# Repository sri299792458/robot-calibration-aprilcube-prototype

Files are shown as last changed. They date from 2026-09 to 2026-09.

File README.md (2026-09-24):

# G1 camera calibration and fixtures

Calibration capture and analysis tools, with printable marker mounts for the
head-mounted RealSense and Dex3 hands on the Unitree G1.

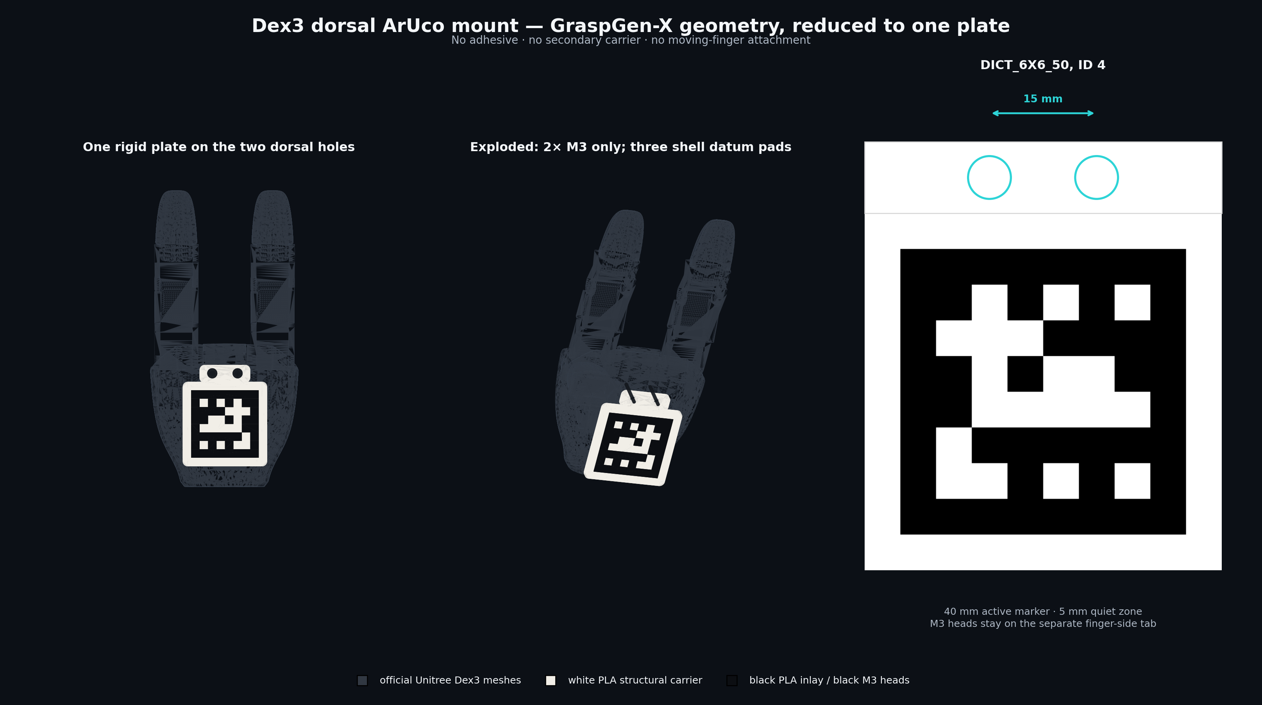
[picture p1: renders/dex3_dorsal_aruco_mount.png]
CAD view of the Dex3 dorsal marker mount, fasteners and marker geometry


*Right-hand wrist-marker mount: CAD placement and attachment geometry. See the
guide for photographs, print files and fitting details.*

**[Calibration workflow](https://sri299792458.github.io/g1-research-docs/calibration/workflow.html)** ·
[Full G1 guide](https://sri299792458.github.io/g1-research-docs/) ·
[Documentation source](https://github.com/sri299792458/g1-research-docs)

Use this repository to capture camera/joint observations, fit and evaluate a
calibration, or reproduce the wrist-marker fixtures. It includes both wrist
mounts, the selected August calibration bundle, and the later V7 torso mount
with R2 fit coupons. The V7 assembly still has
[physical fit limits](artifacts/g1_mount_v7/FIT_STATUS.md).

Physical cube stacking, control integration and episode recording live in
[g1-dex3-tabletop](https://github.com/sri299792458/g1-dex3-tabletop).
Generic printed targets and detection live in the
[AprilCube fork](https://github.com/sri299792458/aprilcube).

## Choose a starting point

| Task | Files to open |
| --- | --- |
| Print or fit a wrist marker | [Mount guide](docs/dex3_dorsal_aruco_mount.md), [right ID 4](cad/dex3_dorsal_aruco_mount/), [left ID 5](cad/dex3_dorsal_aruco_mount_id5/) |
| Inspect the current torso mount | [V7 guide](artifacts/g1_mount_v7/README.md), [physical fit status](artifacts/g1_mount_v7/FIT_STATUS.md), [R2 coupons](artifacts/g1_coupon_r2/README.md) |
| Edit native torso CAD | [Fusion/mesh script guide](scripts/G1_MOUNT_README.md), [native archive](artifacts/g1_mount_v7/cad/G1_calibration_mount_native.f3d), [STEP](artifacts/g1_mount_v7/cad/G1_calibration_mount_assembly.step) |
| Inspect the selected calibration | [Bundle guide](docs/calibration-bundle.md), [bundle JSON](config/calibrations/dex3_shared_20260812_selected_free.json) |
| Understand capture and native fitting | [CLI reference](docs/calibration-cli.md), `src/g1_aprilcube_calibration/session_store.py`, `dataset_builder.py`, `robot_calibration_bridge.py`, `calibration_evaluation.py` |
| Understand control handback | [Commissioning evidence and recovery](docs/g1_control_state_and_recovery.md), [current guide](https://sri299792458.github.io/g1-research-docs/control/ownership.html) |

## What is established

The wrist targets use 40 mm `DICT_6X6_50` markers, right ID 4 and left ID 5.
Their matched profiles enforce the arm and marker identity. The two palm frames
have different dorsal directions; use the handed transforms in
`src/g1_aprilcube_calibration/dex3_dorsal_mount.py`.

The August 12 bundle preserves the shared-camera fit and selected joint offsets
used by the August 25 stacking baseline. Its original validation record reports
model-fit evidence, not an independent accuracy specification for another robot.
The bundle materializes a separate calibrated URDF and checks the original
URDF's hash. It does not require the original recordings to be present.

V7 is the current torso structure: two broad crossbars and two side plates
supporting the existing 210 × 300 mm carrier. Its 180 × 270 mm ChArUco pattern
and four M4 holes are preserved. Recorded CAD checks are available alongside
the exports. **The complete V7 assembly has not been physically qualified.**
Upper M6 × 25 worked in the reported R2 coupon trial; lower M6 × 25 did not
engage through the coupon. Lower screw length, upper engagement details,
assembly stiffness, reinstall repeatability and calibration accuracy remain
unresolved. Consult the fit status before choosing hardware.

The pre-R2 meshes under `original_reference/` and `precision_reference/` are
inputs to the comparison checks. Current print files are under `print_parts/`
and `fit_coupons/`; reference meshes are not alternative current designs.

## Offline setup

CAD exports and the supplied Bambu projects can be opened without installing the
Python package. The Python tools expect two independent checkouts at the root:

```bash
git clone https://github.com/sri299792458/aprilcube.git aprilcube
git -C aprilcube checkout --detach 80ed7c72ed00aef6dc70f77d8169a199e9a612cd
git clone https://github.com/unitreerobotics/unitree_ros.git unitree_ros
git -C unitree_ros checkout --detach f3772ce54c56ef2d34c6aee8100bc768896c7d19
uv sync --python /usr/bin/python3 --group dev
```

These are the revisions used by the inspected calibration checkout. Keep the
system interpreter aligned with ROS for later hardware use: Python 3.10 for
Humble or Python 3.12 for Jazzy, with NumPy 1.x. The editable AprilCube dependency
and its models must be available before `uv sync`.

An offline bundle inspection creates no robot connection:

```bash
.venv/bin/g1-calib inspect-calibration-bundle \
  --calibration-bundle config/calibrations/dex3_shared_20260812_selected_free.json \
  --urdf config/urdf/g1_29dof_rev_1_0_g1pilot_collision.urdf
```

The Fusion scripts require Autodesk Fusion's `adsk` API. Mesh checks and Bambu
comparisons have additional dependencies described in their
[script guide](scripts/G1_MOUNT_README.md). Running a CAD builder changes its
active design; opening an exported model does not require running a builder.

## Repository boundaries

`src/`, `tools/`, and `tests/` retain the calibration implementation and its
regressions. `config/` contains matched profiles and upstream pins. `cad/` and
`artifacts/` contain the current fixtures, their source assets and recorded CAD
checks. The included tests are offline contracts; passing them does not
commission a hardware command or validate a physical mount.

Raw recordings, experiment work directories, private running notes and internal
design proposals are kept outside the public tree. Paths under `sessions/`,
`runs/`, or `work/` in provenance identify retained source evidence; they are not
downloads bundled with this repository. Selected manipulation datasets are
released separately in LeRobot format after conversion and review.

Generated handoff ZIPs are not duplicated in Git. The packaging scripts can
assemble them from the maintained files. Existing upstream notices, including
the Unitree model license with the frozen V7 inputs, remain with those assets.

Research and original implementation by
[sri299792458](https://github.com/sri299792458), building on Unitree, AprilCube
and Mike Ferguson's `robot_calibration`. This consolidation retains the V7
implementation and the local calibration-bundle addition without importing
private development history.

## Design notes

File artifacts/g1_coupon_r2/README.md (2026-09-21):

# Compact G1 fit coupons — R2

Use these revised coupons for the first shell-fit and M6 screw-reach check. All four together are estimated at **19.8 g and 43 minutes**, versus **61.6 g and 100 minutes** for the original coupons with the same settings. That is approximately **68% less filament**. These are Bambu Studio estimates, not a completed print measurement.

The full 28 × 28 mm curved contact patch, 6.8 mm M6 bore, and original washer bearing position are retained. The old 34 mm outer block and deep access well are removed. Upper coupons are now about 22.5–22.8 mm high; lower coupons about 15.1 mm. The four structural mount parts are unchanged.

## Physical fit status

These coupons have now been tried. The user reports M6 × 25 works at the upper locations but does not engage at the lower locations with coupons installed. Lower screw length is unresolved, upper engagement and washer details are unmeasured, and all four CAD seats remain 12 mm at the screw axis. The M6 × 20 example below is nominal geometry, not a hardware recommendation. See [FIT_STATUS.md](FIT_STATUS.md).

## Print

Open `G1_R2_fit_coupons.3mf` in Bambu Studio for all four coupons on one plate, or load the individual STLs in `print_parts/`. Keep the supplied orientation and 100% scale. The marked flat face goes on the bed; the curved face prints upward.

The supplied profile uses an H2D with a 0.4 mm standard nozzle, Bambu PLA Basic, 0.20 mm layers, **three walls, 10% gyroid infill and four top/bottom layers**, without supports or a brim. Use the actual filament profile for your material before printing; its time estimate can differ. The engraved marks span at most 4 mm on the underside and create small bridges. The main M6 bore is vertical in print orientation.

## Identify and fit

The triangle on the flat washer side points toward the robot's head when installed. Dots on that same side identify the location:

| Dots | Robot location |
| ---: | --- |
| 1 | Upper left |
| 2 | Upper right |
| 3 | Lower left |
| 4 | Lower right |

Left/right refer to the robot's own sides. `renders/identification_marks.png` shows the markings.

Place the curved face against the matching location on the installed silver shell, arrow upward. Use the intended M6 screw and washer, and tighten only gently for the fit check. Check for rocking and verify usable thread engagement and clearance before the screw bottoms out. These coupons retain the nominal 12 mm center stack: M6 × 20 with a 1.6 mm washer projects approximately 6.4 mm beyond the modeled outer shell, before subtracting any unmeasured insert recess.

These are individual fit gauges. They do not validate the assembled crossbar's hole spacing, simultaneous seating, deep tool access, stiffness or calibration accuracy.

## Verification

All four STLs are watertight single solids and sit at Z = 0 in their print files. The CAD revision only trims away material in front of the contact patch and outside its footprint, then adds shallow markings away from the washer. Across 1,592 contact samples per coupon, the revised meshes agree with fresh exports of the original crossbars within 0.038 mm (0.05 mm comparison tolerance); all 96 sampled washer-seat points per coupon agree, and every screw centerline is clear. Native Fusion has no feature errors or warnings. Detailed records are in `geometry_qa.json` and `slicer_comparison.json`.

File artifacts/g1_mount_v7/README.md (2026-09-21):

# G1 torso calibration mount — native Fusion redesign

Status: mechanically motivated CAD prototype for stationary calibration. The four structural parts have passed the recorded geometry and clearance checks. R2 coupons have been printed and tried: M6 x 25 reportedly works at the upper locations but does not engage through the lower coupons. Lower screw length, full assembly fit, stiffness, repeatability and calibration accuracy remain unresolved. See [physical fit status](FIT_STATUS.md).

## Design decision

Use two torso crossbars and two flat side plates. The accepted 210 × 300 mm carrier, its four existing M4 holes, the 180 × 270 mm ChArUco pattern and its nominal placement are unchanged.

The failed design had a small offset connection to an M6 boss, which broke during support removal/handling in PLA. This redesign puts each 28 × 28 mm shell seat directly into a continuous crossbar. The side plates have approximately 18 mm rails, a broad rear spine, rounded windows, and fully backed 28 × 12 mm carrier tabs.

The four-part architecture is a deliberate print-orientation choice. Side plates lie on their exterior faces; crossbars lie on their forward faces. The principal long members then lie in their print layers. An integral two-frame alternative reduces screw count but makes the lateral torso attachments harder to orient favorably. The four-part layout is the current recommendation for calibration, not a claim that it is globally optimal.

Eight additional M5 bolts attach the four side-plate/crossbar junctions, two bolts per junction with 20 mm spacing. These are fixed assembly joints. There are no adjustment slots or extra carrier holes. Splitting parts to improve print orientation follows the general approach described in [Prusa's design-for-printing guidance](https://help.prusa3d.com/article/modeling-with-3d-printing-in-mind_164135).

## Files

- `cad/G1_calibration_mount_native.f3d`: native Fusion archive with named sketches, extrusions, lofts, construction planes, imported reference meshes and hidden fit coupons.
- `cad/G1_calibration_mount_assembly.step`: four structural solids in their assembled positions. Reference meshes and hidden coupons are excluded.
- `print_parts/`: four centered, correctly oriented structural STLs, one copy each.
- `fit_coupons/`: four compact R2 interface coupons, centered on the bed. Their full contact patches, M6 bores and washer bearing planes are retained from the crossbars. The unused front block and access wells are removed. See `fit_coupons/README.md` for identification marks and coupon settings.
- `renders/fusion_assembly.png`: assembly shown in Fusion, with the existing board and robot as references.
- `renders/board_connections.png`: centered rear view showing the four board mounting pads.
- `renders/m6_root_section.png`: section through the upper-left M6 connection.
- `renders/print_orientations.png`: broad faces to place on the bed.
- `design_inputs.json`: dimensions, frozen interfaces, camera/board placement and nominal shell samples.
- `mesh_and_clearance_qa.json`, `fusion_assembly_qa.json`, `fusion_interference_qa.json`, `board_contact_qa.json`: verification records.

The original accepted board is included in the Fusion file as reference geometry. It does not need reprinting. Mesh references are not converted into a new optical pattern.

The supplied carrier STLs use print-bed coordinates, translated +15 mm along both board-plane axes. The final Fusion assembly reverses this offset before applying the optical-board transform. Earlier assembly previews omitted that conversion and showed the carrier shifted relative to its supports; the final archive and included previews are corrected.

## Hardware

| Use | Quantity | Hardware |
| --- | ---: | --- |
| Upper torso mounting | 2 | M6 × 25 socket-head screws under physical test; engagement and washer stack unmeasured |
| Lower torso mounting | 2 | M6 socket-head screws; length unresolved. M6 × 25 does not engage through the R2 coupons |
| Torso washers | 4 | M6 flat washers, approximately 1.6 mm thick, maximum 13 mm OD |
| Existing board attachment | 4 | M4 × 30 socket-head screws |
| Board washers and nuts | 8 + 4 | M4 flat washers and M4 nyloc nuts |
| New frame joints | 8 | M5 × 30 socket-head screws |
| New frame washers and nuts | 8 + 8 | M5 flat washers, approximately 1 mm thick, and standard M5 hex nuts |

The M5 nut slots are 4.4 mm thick and 8.3 mm across the retaining flats. They are for ordinary approximately 4 mm thick M5 hex nuts, not taller nyloc nuts. Load the nuts through the forward-facing slots and insert each bolt from the exterior of the side plate.

The M5 stack leaves approximately 3.8 mm of bolt protrusion beyond the modeled inner nut face. Check the actual nut/washer dimensions before assembly. All tightening is through washers and printed material; use a short hand tool and stop before compressing or deforming the print. Witness-mark the joints and inspect for loosening.

The earlier M6 × 20 assumption is superseded by the physical results. No deeper lower washer recess or M5 × 20 conversion has been made. See [FIT_STATUS.md](FIT_STATUS.md) before selecting hardware.

### M6 reach is not the same as engagement

At each M6 center the modeled shell-to-washer-face distance is 12 mm. A 20 mm screw with a 1.6 mm washer therefore projects about **6.4 mm past the modeled outer shell**. Actual threaded engagement is reduced by any recess before the first usable thread. The handoff does not measure that recess or the blind-hole clearance.

Do not assume 6.4 mm of thread engagement, use screw bottoming as a datum, or substitute a longer screw without measuring the usable depth. A screw that merely begins to clamp is not proof of adequate engagement. Record both thread-start depth and available bottom clearance with each fit coupon before finalizing the M6 length.

## Print and assembly

1. Print the four compact R2 fit coupons first, using 0.20 mm layers, three walls, four top/bottom layers and 10% gyroid infill in PLA. Each retains the seating face, M6 bore and washer bearing plane. The deep tool well is removed. Fit the matching coupon with its arrow pointing up and the normal silver shell installed. Dot counts identify 1 upper-left, 2 upper-right, 3 lower-left, 4 lower-right, using the robot's own left/right.
2. Check full seating without rocking, adequate measured screw engagement and clearance before bottoming. The shell must not shift or spring against internal foam under light clamping. Compact coupons test individual seats and screw reach; the full crossbar hole spacing, simultaneous seating and deep tool-access corridors still need checking with the actual crossbars.
3. After the coupons pass, print the four structural STLs in their provided orientations. Centering in the slicer is fine; preserve rotation and 100% scale. One side plate per bed. Both crossbars can share a bed if the slicer confirms spacing.
4. Start with PLA or PLA+, 0.20 mm layers, six walls, six top/bottom layers and 35% gyroid infill. These are starting settings, not a tested printer profile. There are no detached bosses or large unsupported carrier tabs. Inspect the short horizontal holes and the M6 counterbore ceilings in the slicer; small bridges remain. Do not enable support that will be trapped in a well or nut slot.
5. Assemble the crossbars and side plates loosely with the eight M5 bolts. Fit the existing board against the four carrier tabs and install its four M4 bolts, washers and nyloc nuts. Keep all joints loose until every interface seats naturally; do not pull misaligned parts together with screw torque.
6. Mount on the stationary robot, then snug the joints progressively without bowing the board or crushing the PLA. Record the tightening sequence and witness marks for repeatable reassembly.

The side plates measure approximately 238.1 × 271.4 × 34.5 mm in print orientation. Upper and lower crossbars measure 230 × 40 × 53.1 mm and 230 × 40 × 37.6 mm. All fit within the handoff's conservative 300 × 320 mm bed area.

PLA remains the baseline. A change to PETG changes stiffness and printing behavior and does not replace the fit and flex checks. The fixture is for stationary calibration; remove it before robot walking, waist motion or arm trajectories.

## Recorded CAD checks

- Four structural STLs and four coupons: watertight, consistently oriented, one connected solid each.
- Native Fusion timeline: no feature errors or warnings at export.
- Four native structural solids: zero volume interference; coincident mating faces excluded.
- Full active target: 49,051 rays at 1 mm spacing from the supplied fitted camera pose, zero obstruction.
- Four M6 corridors: a sampled 14.4 mm diameter, 90 mm long straight approach is clear.
- Four M4 locations: optical-side and rear nut approach centerlines are clear.
- Existing carrier to support pads: all four screw centerlines align; 72 sampled points around each hole match the carrier's bearing face within 0.02 mm mesh tolerance. This checks nominal CAD contact, not printed fit.
- Eight M5 centerlines: plate and crossbar holes are aligned and clear.
- Nominal shell approximation: 96 contact samples per root; maximum absolute sampled difference from the public shell is approximately 0.113 mm. This is only CAD approximation error, not physical robot accuracy or a complete surface-tolerance certification.

R2 coupon fit observations are recorded in FIT_STATUS.md. No FEA, complete V7 structural assembly trial, creep test, measured stiffness test or calibration capture has been performed. The full-density structural CAD volume corresponds to about 1.01 kg of PLA at 1.25 g/cm³, excluding the accepted carrier and metal hardware. This is an upper bound for solid prints, not a slicer mass estimate. The corresponding structure-only gravity moment about the M6 pattern is approximately 0.78 N·m; it is not a load rating.

## Calibration acceptance for tabletop work within a few millimetres

The intended camera extrinsic remains:

`torso_T_camera = torso_T_board × inverse(camera_T_board)`

The nominal board center is `[245, 0, 127.5]` mm in `torso_link`, pitched +21° about torso y. The active outer top-left corner defines the OpenCV board origin. The complete transform is in `design_inputs.json` in millimetres; convert translation to metres when using the calibration code.

Use these as initial acceptance targets, not achieved specifications:

- Active pattern dimensions remain 180 × 270 mm; measure both axes and diagonals. Check mounted face bow, initially targeting less than 0.5 mm.
- Live rectified color detects all 27 markers and 40 ChArUco corners without fixture obstruction.
- With the camera fixed, collect stationary bursts across at least five full fixture removal/reinstall cycles. Aim for board-pose variation below 0.5 mm and 0.1°. If it exceeds those targets, investigate seating, shell compliance, bolt slip and board flex before accepting the calibration.
- A 0.1° rotation error produces about 0.87 mm lateral error at 0.5 m, before translation and other errors. Evaluate the budget at the actual working distance.
- Reinstall repeatability does not establish absolute accuracy. Independently check the installed board's relationship to a torso datum and validate the result on a separately measured tabletop target or task points. Neither CAD coordinates nor low image reprojection error alone prove millimetre accuracy.

The interface remains nominal until the physical observations are recorded. Keep those observations and the installed transform separate from the source CAD values.

## Editing

The four structural parts are native solids with editable feature history. The supplied Python builders make the fixed interface coordinates explicit. Changing an extrusion or sketch can invalidate the assembled mating faces, screw stack or optical clearance; regenerate and rerun the checks after geometry changes. The single plate-thickness user parameter is not a complete assembly-level constraint system.

The packaging scripts can generate a review ZIP with copies of the V7 scripts in `source/`; generated ZIPs are kept outside Git. Their paths resolve from the repository checkout; they are not a one-click installer. Frozen inputs are in `reference_inputs/`; geometry construction runs inside Fusion. See [the repository script guide](../../scripts/G1_MOUNT_README.md) for dependencies and execution context. Scripts included under `source/` in a generated ZIP are provenance copies; run them from the repository `scripts/` folder. The native F3D file is self-contained and can be opened without these scripts or Python dependencies. For slicing, use `print_parts/` and `fit_coupons/`; the raw STLs under `cad/` retain their modeling coordinates.

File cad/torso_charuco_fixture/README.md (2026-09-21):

# Accepted printed carrier

This folder contains only the accepted carrier used by the
[current V7 torso mount](../../artifacts/g1_mount_v7/README.md):

- `carrier_white_body.stl`
- `carrier_black_inlay.stl`
- `carrier_multicolor_h2d.3mf`
- `design_manifest.json`: carrier definition and frozen mounting coordinates

The already printed carrier does not need to be printed again. Its original
mesh and 3MF bytes are unchanged. The previous V6 side frames, coupons and
generator have been removed. The current structural parts and fit coupons
are in `artifacts/g1_mount_v7/` and `artifacts/g1_coupon_r2/`.

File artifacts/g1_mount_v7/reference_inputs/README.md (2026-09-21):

# Geometry inputs for the current mount

Carrier geometry and mounting coordinates derive from source commit
`b555c3adea33966607c26837264230dbc1208c6c`; see `PROVENANCE.md`.
The carrier meshes match the retained accepted meshes under
`cad/torso_charuco_fixture/`. The manifest has been reduced to the carrier
definition and frozen input coordinates; previous frame and hardware
instructions are removed. `reference_code/config/torso_fixture_layout_camera.json`
matches the repository's measured camera configuration semantically.

The robot mesh and URDF reference files carry the upstream license included
as `robot_model/UNITREE_ROS_LICENSE`. This partial snapshot is sufficient
for the mount scripts, not a complete robot simulation model.

Use `../README.md` and `../FIT_STATUS.md` for current design and hardware status.

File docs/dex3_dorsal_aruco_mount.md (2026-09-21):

# Dex3 two-hole dorsal ArUco mount

## Result

The mount is a **single 50 x 50 mm optical plate with a centered 30 x 10 mm
finger-side mounting tab**, fixed directly to the two holes in the rigid Dex3
palm shell. Its overall envelope is 50 x 60 mm. It carries a two-filament 40 mm
`DICT_6X6_50` marker, right ID 4 or left ID 5. There is no tape, intermediate bracket, snap joint,
or attachment to a moving finger.

This is the pitch-corrected second revision. The first physical print proved
that the former 2.0 mm wrist pad did not contact the hand. That design assumed
the plate was parallel to the palm-link plane. The local M3 mounting surface is
actually pitched by approximately 1.143 degrees. Revision 2 follows that pitch
and uses a 2.57 mm third datum on the flatter central shell region.

Rendered mount on the official Dex3 geometry

The printable H2D file is
[`dex3_dorsal_aruco_mount_multicolor_h2d.3mf`](../cad/dex3_dorsal_aruco_mount/dex3_dorsal_aruco_mount_multicolor_h2d.3mf).
Print the small
[`m3_15mm_fit_coupon.stl`](../cad/dex3_dorsal_aruco_mount/m3_15mm_fit_coupon.stl)
first.

### Left and right files

Use separate IDs when both hands can appear in the image. The mechanical
envelope and mounting hardware are shared; the detector profile and palm-frame
transform are handed.

| Hand | Marker | CAD directory | Matched target profile |
| --- | --- | --- | --- |
| Right | ID 4 | `cad/dex3_dorsal_aruco_mount/` | `config/dex3_dorsal_aruco_target.json` |
| Left | ID 5 | `cad/dex3_dorsal_aruco_mount_id5/` | `config/dex3_left_dorsal_aruco_id5_target.json` |

Generate the left files from the repository root without replacing the right:

```bash
.venv/bin/python tools/generate_dex3_dorsal_aruco_mount.py --marker-id 5 --side left
```

Check the `side` field and transform in each generated `design_manifest.json`.
The right marker faces toward negative palm Y; the left faces toward positive
palm Y. The ID 4 examples and numeric transform below describe the right hand;
use the left profile and generated transform for ID 5.

## What is established, and what is inferred

The design does not pretend that the public Unitree model contains data that it
does not contain.

| Item | Status | Evidence |
|---|---|---|
| Target family | Established | The marker in the original GraspGen-X project video decodes as OpenCV `DICT_6X6_50`, ID 4, across multiple frames. |
| Target form | Established | Video frames show a flat, roughly 50 mm dorsal plate on the right Dex3. |
| Palm frame and outside surface | Established | Official Unitree `right_hand_palm_link.STL` and Dex3 URDF. The central dorsal region is shallowly curved: less than 0.9 mm departure from a plane over the proposed footprint. |
| Two physical holes | Established | Supplied photograph of the actual Dex3. |
| Hole pattern | **Official dimension** | Unitree's Dex3-1 user manual calls out `2 x M3`, 3 mm deep, on 15.00 mm centers. An M3 screw was also checked directly in the real hand. |
| Hole midpoint in `*_hand_palm_link` | **Official drawing + official mesh** | The manual places the pair centerline 66.70 mm from the wrist-side datum and on the hand centerline. The URDF/mesh establishes that as palm `[x, z] = [66.70, 0] mm`; ray intersection gives the dorsal shell at approximately `y = -21.33 mm`. |

The tiny coupon remains useful because FDM holes often print undersize. It now
checks printer clearance against an official 15.00 mm pattern rather than
testing an image-derived estimate.

The reproducible measurements are recorded in
[`graspgenx_dex3_mount_evidence.md`](../references/graspgenx_dex3_mount_evidence.md).
The raw downloaded video was analysis material and is not required by the CAD.
That evidence record also documents the search of Unitree's public CAD, model,
URDF, USD, historical mesh releases, and the image-based Dex3 user manual. The
URDF mesh omits the holes, but the manual supplies their missing dimensions.

## Geometry

| Feature | Dimension |
|---|---:|
| Carrier envelope | 50 x 60 x 4.0 mm |
| Optical square / centered mounting tab | 50 x 50 mm / 30 x 10 mm |
| Corner radius | 3.0 mm |
| Active ArUco square | 40.0 mm |
| Quiet zone | 5.0 mm on every side |
| Marker grid | 6 x 6 payload + one-cell black border |
| Cell size | 5.0 mm |
| Black inlay depth | 0.6 mm |
| Hole center spacing | 15.00 mm, official drawing |
| Hole pair centerline from wrist datum | 66.70 mm, official drawing |
| Blind-hole specification | 2 x M3, 3.0 mm deep |
| Through clearance | 3.4 mm |
| 90-degree countersink | 6.0 mm major diameter, 1.7 mm deep |
| Screw-line distance from finger-side tab edge | 5.0 mm |
| Material ligament around each 6 mm head, fore/aft | 2.0 mm / 2.0 mm |
| Local mounting pitch from palm STL | 1.143 degrees |
| Rear screw bosses | 7.0 mm diameter x 1.5 mm high |
| Rear stabilizing datum | 6.0 mm diameter x 2.57 mm center height |
| Stabilizing datum location | 20.0 mm from wrist-side optical edge |
| Stabilizing datum face correction | 1.994 degrees relative to plate |

The screw centers are on the separate 10 mm tab. Even the complete 6 mm heads
remain beyond the 50 mm optical square, so neither the black border nor its 5 mm
white quiet zone is interrupted. The line of screws sits next to the finger
bases and the complete marker extends toward the wrist. This keeps both metal
heads and the target away from the moving finger links.

The 10 mm tab depth is intentionally not reduced further. A centered 6 mm
countersink leaves 2 mm of PLA toward the optical plate and 2 mm toward the
outer edge. Reducing the overall length to 58.5 mm would save only 1.5 mm while
cutting the marker-side ligament to 0.5 mm, an undesirable stress concentration
next to a clamped countersunk screw.

The two annular screw bosses and one central circular pad form a three-point
seat. This is deliberate: the official shell is curved, so a nominally flat
back would rock or bend when tightened. Three small hard datums are the usual
fixture-design solution because they establish one plane without overconstraint.
The third datum is now only 35 mm from the screw line rather than 45 mm. It is
still wristward of the marker center, so the marker's center lies inside the
support triangle, but the pad no longer reaches onto the more strongly curved
wrist end of the shell.

The palm-STL tangent over the two screw-boss footprints has `dy/dx = 0.019947`.
The fitted tangent over the third pad is `dy/dx = -0.01485`. Those two slopes
set the installed plate pitch, the 2.57 mm pad height, and its angled contact
face. The nominal pad-center discrepancy from the STL surface is below 0.001
mm; printing tolerance, not the CAD equation, is now the limiting factor.

## Exact hardware

Use:

- 2 x **M3 x 8 mm, ISO 10642, 90-degree countersunk socket-head machine
  screws, black oxide**;
- one 2.0 mm hex key;
- white PLA and matte black PLA.

The printed stack from the flush head face to the hand shell remains 5.5 mm: 4.0 mm
plate plus a 1.5 mm rear boss. An M3 x 8 screw therefore enters by 2.5 mm,
leaving 0.5 mm before the conservative 3.0 mm blind-hole bottom. Do not
substitute M3 x 10: it can bottom in the blind hole. Do not use a washer; the
countersunk head is the intended plate datum.

The thread size has already been confirmed with an M3 screw. When assembling,
still start both screws by fingers only; this avoids cross-threading the shallow
blind holes.

## Print on the Bambu H2D

1. Print the fit coupon in any PLA using a 0.4 mm nozzle and 0.20 mm layers. It
   should take only a few minutes and checks printer tolerance and center
   spacing, not the already-confirmed thread designation.
2. Put two loose M3 screws through the coupon. Both screws must enter the hand
   holes without bending the coupon or pushing either screw sideways.
3. Open the multicolor 3MF as one object with two parts. Assign
   `carrier_white_PLA` to white and `aruco_black_PLA` to matte black.
4. Keep the generated orientation: the marker face is on the build plate and
   the three datum pads point upward. A smooth PEI plate gives the cleanest
   optical face. No support is required.
5. Use a 0.20 mm layer height, four walls, and at least five top/bottom layers.
   The 0.6 mm inlay occupies exactly three nominal layers.
6. Do not rescale either part and do not separate their origins.

Separate white and black STLs are included for slicers that do not preserve the
3MF material assignment.

## Assembly

1. Power the robot off and make sure no finger can move.
2. Place the plate with the screw line toward the finger bases and the long
   portion of the plate extending toward the wrist.
3. Start both M3 x 8 screws by hand before tightening either one.
4. Tighten alternately with the short end of the 2.0 mm key. Stop as soon as all
   three rear pads are seated and the plate no longer rocks. This is a marker,
   not a structural payload bracket; high torque only risks the Dex3 threads.
5. Verify that the plate clears both proximal finger links throughout their
   slow, powered-off manual range before commanding the hand.
6. In the detector, configure `DICT_6X6_50`, ID 4 (right) or ID 5 (left), and a marker side length of
   exactly `0.040` metres.

After assembly, take one close photograph square to the marker. The detector
must recover the intended hand's ID with all four corners. The screw heads are outside the optical
square and should never enter the detected quadrilateral.

## Marker transform

The generated manifest records this nominal target frame:

```text
marker +x = [ 0,          0,          1 ] in the palm frame
marker +y = [-0.999801,  -0.019943,   0 ] toward the wrist
marker +z = [ 0.019943,  -0.999801,   0 ] outward from the marker face

palm translation to marker center = [0.03681565, -0.02742720, 0.0] m
```

The longitudinal and lateral coordinates come from Unitree's official
dimensioned drawing, not photograph registration. The outward coordinate and
1.143-degree plate pitch use the official palm mesh at the documented hole
positions. This is the transform to use for the planned camera-only solve after
the physical seating and fixed-transform validation checks. Keep the optional
joint camera/marker solve available as a diagnostic comparison rather than the
production result.

The CAD is parametric. After measuring a different center spacing, regenerate
it with:

```bash
uv run python tools/generate_dex3_dorsal_aruco_mount.py \
  --hole-spacing-mm MEASURED_SPACING
```

The generated plate occupies a local 50 x 60 x 6.675 mm print envelope before
its palm-frame mounting transform is applied. Add the resulting pitched object
to any motion-planning model before using the marked hand near the torso, table,
or the other arm.

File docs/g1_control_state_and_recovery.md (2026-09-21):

# G1 control state and debug-lowcmd recovery

This is the operator runbook for the control behavior physically observed on
this G1. Keep the distinction between the active **motion service**, the
locomotion **FSM ID**, and LowState `mode_machine`; they are different state.

## State vocabulary

| State | Meaning on this robot |
|---|---|
| Motion service `{"form": "0", "name": "ai"}` | The normal Unitree high-level controller is active. The wireless remote and G1 locomotion client can request FSM transitions. |
| No active motion service | Unitree `ReleaseMode()` has made direct debug `rt/lowcmd` ownership available. This is not an FSM such as Damp or Seated. |
| FSM 0 | Zero-torque state observed when the `ai` service was restored after a failed debug session. |
| FSM 1 | Damp. |
| FSM 3 | Seated. |
| FSM 4 | Regular/Ready on this robot. |
| LowState `mode_machine=5` | The 29-DoF G1 machine/joint layout. It is not locomotion FSM 5. |

Selecting the `ai` motion service does **not** select Damp, Seated, Ready, or
Walking. It only makes the high-level controller available. An explicit FSM
request and a read-back are still required.

## Why the remote can become unresponsive

The seated tabletop controller follows Unitree's debug architecture:

1. verify the robot starts in seated FSM 3;
2. call MotionSwitcher `ReleaseMode()` to deactivate `ai`;
3. publish a complete measured-state 29-joint command on `rt/lowcmd`; and
4. before closing that publisher, restore `ai` and explicitly verify the
   requested terminal FSM.

While `ai` is released, the wireless remote has no active high-level controller
to receive its FSM requests. The G1 locomotion client's read-only `get_fsm_id`
may also time out. This does not by itself indicate a failed Ethernet link or a
dead remote.

If the lowcmd process exits without restoring `ai`, both of these can be true at
once:

- no laptop lowcmd writer remains; and
- no normal Unitree motion service is active.

The result looks like a zero-torque/debug state and the remote cannot select
another FSM until `ai` is restored.

## Hardware observation: 2026-08-10

The zero-displacement seated commissioning run established the following:

- PC2 verified initial seated FSM 3;
- the dynamic handoff passed;
- the laptop released the active service;
- the first complete measured-state `rt/lowcmd` packet was accepted; and
- no changing joint target was part of the test.

The run then failed because PC2 stopped receiving the laptop heartbeat. Its
fallback attempted to restore the motion service, but MotionSwitcher read-only
API 1001 (`CheckMode`) timed out three times. PC2 therefore could not proceed to
a verified Damp request. The lowcmd process exited with `ai` still released,
and the wireless remote could not change modes.

Restoring `ai` from the laptop with Unitree's official SDK succeeded and
reported:

```text
motion service restored: {'form': '0', 'name': 'ai'}
```

The robot then entered the observed zero-torque FSM 0. It did not automatically
enter Damp or return to Seated. The wireless remote became usable again.

This run proved zero-displacement debug takeover, but at that point it did
**not** commission normal seated restoration, heartbeat-loss zero-torque
recovery, or changing-target arm motion. The later lifecycle checks recorded
below closed the first two gaps.

A second zero-displacement run after the first software changes narrowed the
failure further:

- PC2's new read-only preflight succeeded while `ai` was active and reported
  `motion_switcher=ai` together with seated FSM 3;
- the heartbeat guard covered `ReleaseMode()` and completion of the first
  measured-state lowcmd write;
- the first packet again passed and no changing target was commanded;
- the heartbeat nevertheless expired during the subsequent hold; and
- once `ai` had been released, PC2 MotionSwitcher API 1001 timed out again on
  every fallback attempt.

This established an important asymmetry on the installed stack: PC2's ROS
MotionSwitcher path could answer `CheckMode` before service release but could
not be relied upon to answer after release. The laptop's raw Unitree SDK did
successfully verify the released state during takeover and later restored
`ai`. The watchdog therefore stopped using the PC2 ROS MotionSwitcher path for
debug recovery. It creates a persistent client from the pinned raw SDK runtime
before takeover and reuses that same client after release. This replacement was
installed and tested offline before the later physical lifecycle checks
commissioned its post-release behavior.

A third zero-displacement run used that private raw-SDK runtime. It established
four additional facts:

- PC2 received one ping and expired at 0.500258 seconds, while the laptop later
  reported a maximum send gap of 0.922032 seconds;
- the gap occurred before takeover during blocking laptop-side MotionSwitcher
  client and lowcmd-publisher initialization, not during the 250 Hz hold loop;
- PC2's raw `SelectMode("ai")` request did take effect—the robot returned to its
  observed zero-torque state and the remote became responsive—even though the
  RPC reply was reported as status 7002; and
- the subsequent automatic Damp RPC did not complete.

Accordingly, every non-commanding local DDS endpoint is now initialized before
the short PC2 heartbeat lease is armed. Debug-lowcmd failure recovery no longer
chains an automatic Damp request after AI restoration. It restores `ai` and
requires the locomotion service to report FSM 0. The standing `rt/arm_sdk`
workflow retains its independently commissioned terminal Damp fallback.

A fourth zero-displacement run then verified the heartbeat correction:

- the laptop sent 34 pings with a maximum gap of 0.104117 seconds, safely below
  the 0.5-second PC2 lease;
- no heartbeat timeout occurred;
- PC2 restored `ai` and repeatedly read FSM 0; and
- a direct Sit request did not change FSM 0 to FSM 3.

This supports the operator's transition model: clean seated restoration must
use `FSM 0 -> Damp/FSM 1 -> Sit/FSM 3`, verifying every state. This chain is
used only after the arm has returned to the measured, table-supported start.
Fault or heartbeat-loss recovery stops at verified FSM 0 and does not continue
through Damp or Sit. If clean restoration reaches FSM 1 but cannot reach FSM 3,
the installed PC2 locomotion client supports an explicit ZeroTorque request so
cleanup can return to verified FSM 0.

The final two zero-displacement commissioning runs passed both terminal
lifecycle paths:

- normal completion reported `PC2 verified AI FSM 0 -> 1 -> seated FSM 3
  before the lowcmd publisher closed`; and
- deliberate heartbeat loss reported `PC2 verified AI service in zero-torque
  FSM 0 before the lowcmd publisher closed`.

Both runs had already passed dynamic handoff, service release, the first
complete measured-state lowcmd packet, and the zero-displacement hold. These
results physically commission debug ownership, normal seated restoration, and
independent heartbeat-loss recovery. They did not claim changing-target motion;
at that point the first fully preflighted tabletop route was still the next
changing-target seated test. The reviewed repository configuration now sets
`control.seated_debug_lowcmd_commissioned: true`.

## Changing-target result and gravity-feedforward follow-up

A later complete seated table route physically verified changing left-arm
targets, image capture at the elevated target, reversal to the supported start,
and clean AI/FSM 0 -> Damp/FSM 1 -> Sit/FSM 3 restoration. Direct visual
scoring showed that the requested 100 mm lift achieved about 71.1 mm. The task
error was 29.0 mm total, including 28.9 mm vertical error; the seven-frame
measurement itself was repeatable to 0.524 mm and 0.183 degrees. At the table
target, the largest joint error was 0.0495 rad at left shoulder pitch. The run
used Unitree's pinned position gains but wrote zero to every arm `tau` field.

The pinned Unitree XR implementation does not use position PD alone. Its G1
IK code evaluates Pinocchio `rnea(q_command, 0, 0)` and its arm controller writes
the returned values to each motor's `tau` feedforward field. The local seated
controller now implements that same term using the exact configured 29-DoF
rubber-hand URDF, while freezing legs and waist at the measured takeover pose.
At the recorded table target, the local model predicts left-arm gravity torques
of approximately `[-3.121, -0.115, +0.870, -1.444, +0.335, -0.026, +0.176]`
Nm. The observed PD term at the settled pose was approximately
`[-3.959, -0.034, +0.619, -1.666, +0.782, +0.089, +0.176]` Nm, so the model
explains most—but not necessarily all—of the loaded shoulder offset.

The gravity-feedforward zero-displacement run passed physically on 2026-08-11.
It kept every position target fixed while ramping the model torque from zero to
full. Maximum measured drift across both arms was `0.008317 rad` (`0.4765`
degrees), only 16.6% of the `0.05 rad` commissioning bound. PC2 then verified
AI/FSM 0 -> Damp/FSM 1 -> Sit/FSM 3 before the lowcmd publisher closed. This
commissions the torque ramp and its clean restoration path—not the resulting
tabletop task accuracy. `control.seated_gravity_feedforward_commissioned` is
therefore `true`; the next full table run must measure whether the direct
board-relative vertical and total landing errors improve.

The first gravity-compensated accuracy run exposed a second, separate effect:
the torso/head-camera pose changed during complete lowcmd takeover. A route
computed from the seated locomotion state is therefore stale before its first
changing target. The table executor now performs no IK/FCL solve before
ownership. It acquires and settles at an unchanged measured command, captures a
fresh board/cube burst, rebuilds and validates all four route edges from that
loaded state, and atomically installs the matching pose-set/report hashes. A
second loaded burst rejects movement during planning. The achieved burst is
used only for one-shot scoring; it never corrects the commanded endpoint.

## Recovery when the remote cannot change modes

Prerequisites: the load-bearing harness is engaged, the workspace is clear, and
both arms are physically supported. Restoring a controller may re-enable
torque. Do not rerun the failed lowcmd program while the service state is
unknown.

Run this on the laptop; Codex must not run it on the robot operator's behalf:

```bash
cd /path/to/robot-calibration-aprilcube-prototype && \
CYCLONEDDS_HOME="$PWD/deps/cyclonedds_python_prefix" \
LD_LIBRARY_PATH="$PWD/deps/cyclonedds_python_prefix/lib:${LD_LIBRARY_PATH:-}" \
.venv/bin/python - <<'PY'
import time
from unitree_sdk2py.core.channel import ChannelFactoryInitialize
from unitree_sdk2py.comm.motion_switcher.motion_switcher_client import MotionSwitcherClient

ChannelFactoryInitialize(0, "enp134s0")
client = MotionSwitcherClient()
client.SetTimeout(5.0)
client.Init()

status, mode = client.CheckMode()
if status != 0:
    raise SystemExit(f"CheckMode failed before recovery: status={status}")

name = str(mode.get("name", "")).strip()
if not name:
    status, _ = client.SelectMode("ai")
    if status != 0:
        raise SystemExit(f"SelectMode('ai') failed: status={status}")
    time.sleep(1.0)

status, mode = client.CheckMode()
if status != 0 or not str(mode.get("name", "")).strip():
    raise SystemExit(f"AI service was not restored: status={status}, mode={mode}")

print(f"motion service restored: {mode}")
PY
```

After it reports `name: ai`, confirm that the wireless remote responds. On this
robot service restoration has initialized zero-torque FSM 0. Keep the robot and
arms physically supported; zero torque is limp, whereas Damp adds velocity
resistance. Selecting Damp with the remote is an operator choice after control
has been recovered, not a required second step in automated debug recovery.

Do not repeatedly run `SelectMode("ai")` after it has succeeded. Do not treat
the printed motion-service record as an FSM verification.

## Protections added after the observation

The debug transport now maintains its takeover heartbeat continuously from the
blocking MotionSwitcher release through completion of the first measured-state
lowcmd write. Previously, the temporary guard ended after `ReleaseMode()` and
left the first write outside that protected interval.

The PC2 watchdog also performs its own read-only raw-SDK MotionSwitcher
`CheckMode` preflight while `ai` is still active. If it cannot answer,
commissioning stops before service release and before any lowcmd packet. The
same persistent client is retained for post-release restoration. No further
tabletop execution was allowed until normal restoration and heartbeat-loss
recovery were physically commissioned. The final two zero-displacement runs
verified both paths on hardware, including the corrected heartbeat lifetime.

The replacement runtime is installed under
`/home/unitree/.local/share/g1-aprilcube-watchdog`. PC2 initially lacked the
optional Ubuntu `python3.8-venv` package; the operator installed that standard
package explicitly using temporary hotspot access. The watchdog dependencies
themselves are still downloaded and checksum-verified on the laptop, copied to
PC2 over Ethernet, and installed offline into an immutable versioned venv. They
do not modify system Python, the user-wide site-packages directory, Unitree's
ROS workspace, shell startup files, or boot services.

### Installed private runtime

The runtime installed on 2026-08-10 is:

- immutable runtime ID `98da77c45b9d9931`;
- runtime path
  `/home/unitree/.local/share/g1-aprilcube-watchdog/runtimes/98da77c45b9d9931`;
- active selector
  `/home/unitree/.local/share/g1-aprilcube-watchdog/current`;
- Python 3.8.10 with user-site packages disabled;
- CycloneDDS Python 0.10.2 linked to PC2's existing
  `libddsc.so.0.10.2`; and
- `unitree_sdk2py` 1.0.1 built from pinned revision
  `7c661d27f4ae064ffd0dd633fd9d5b518ef0b508`.

Its manifest is at
`/home/unitree/.local/share/g1-aprilcube-watchdog/current/manifest.json` and
records every source checksum, offline dependency version, and the validation
scope. Installation validation imported the raw SDK bindings only; it did not
create a DDS participant, contact the robot, or send a robot command.

Reinstall or reproduce it from the laptop with:

```bash
cd /path/to/robot-calibration-aprilcube-prototype
./tools/install_pc2_watchdog_runtime.sh
```

The installer downloads and verifies inputs on the laptop, stages them over
Ethernet, builds the ARM64 bindings on PC2, and atomically selects the completed
runtime. Re-running it with the same inputs selects the same runtime ID.

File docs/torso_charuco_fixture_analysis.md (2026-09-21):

# Torso calibration fixture: geometry and evidence

The current mechanical design is the
[V7 native Fusion mount](../artifacts/g1_mount_v7/README.md), using two
crossbars and two flat side plates with the accepted printed carrier.
Current physical observations and unresolved screw lengths are in
[FIT_STATUS.md](../artifacts/g1_mount_v7/FIT_STATUS.md).

## Calibration relationship

For a stationary torso target:

```text
torso_T_camera = torso_T_board @ inverse(camera_T_board)
```

The ChArUco observation supplies `camera_T_board`. The CAD transform supplies
a nominal `torso_T_board`, which must be checked against physical datums.
Reprojection error and repeated images alone do not establish absolute
camera-to-torso accuracy. The intended use is tabletop manipulation within
a few millimetres; the README's repeatability and flatness limits are initial
acceptance targets, not achieved results.

## Preserved interfaces

The camera and front accessory pattern belong to `torso_link`, above the
waist articulation. The design uses the four intended front M6 installation
holes. The nominal spacing is 62.4 mm across the upper row, 64.5 mm across
the lower row, and 194.2 mm between rows.

| Location | Nominal outer shell point in torso coordinates, mm |
| --- | --- |
| Upper left | `[61.7071476, 31.2, 265.0961682]` |
| Upper right | `[61.5783281, -31.2, 265.0961682]` |
| Lower left | `[69.5162713, 32.25, 70.8961682]` |
| Lower right | `[69.4891404, -32.25, 70.8961682]` |

The source drawing was registered to the shoulder-roll axes from the URDF;
the parallel screw axes were intersected with the public exterior shell
mesh. These points are shell intersections, not insert faces or thread-start
positions. The nominal helpers remain in
`src/g1_aprilcube_calibration/torso_board_mount.py`; the input reconstruction
is documented by `tools/recover_g1_front_m6_pattern.py`.

The 210 x 300 mm carrier contains a 180 x 270 mm ChArUco pattern with 30 mm
squares, 22 mm markers and `DICT_5X5_50`. Its four existing M4 coordinates
are frozen. The nominal board center is `[245, 0, 127.5]` mm, at +21 degrees
about torso y. The carrier STL's print coordinates have a +15 mm offset on
both board-plane axes; V7 removes that offset before applying the optical
transform. See `artifacts/g1_mount_v7/design_inputs.json` for the full matrix.

## Verification limits

Recorded geometry checks show four aligned carrier contacts, zero positive
structural volume interference, clear screw/tool approaches, and 49,051
unobstructed active-target rays from the supplied measured camera pose.
These checks do not establish actual shell stiffness, screw engagement,
print stiffness, creep, board flatness or mounted-pose accuracy.

The first physical coupon checks found that M6 x 25 reportedly works at the
top but does not engage through the lower coupons. Upper washer/engagement
details and lower usable thread depth remain unmeasured. All current root
seats are 12 mm at the screw axis; no proposed deeper recess has been
implemented. Hardware remains governed by the physical fit record.

## Sources

- [Unitree G1 user manual](https://marketing.unitree.com/article/en/G1/User_Manual.html)
- [Official Unitree G1 URDF/model](https://github.com/unitreerobotics/unitree_ros/tree/master/robots/g1_description)
- [Frozen input provenance](../artifacts/g1_mount_v7/reference_inputs/PROVENANCE.md)
- [Current CAD verification and acceptance targets](../artifacts/g1_mount_v7/README.md)

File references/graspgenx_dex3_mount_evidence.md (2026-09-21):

# GraspGen-X Dex3 dorsal-mount evidence record

This record preserves the reproducible measurements used for the printable
mount without redistributing the downloaded 29 MB presentation video or the
user's full-resolution physical photograph.

## Sources

- GraspGen-X project: <https://graspgenx.github.io/>
- Original project video:
  <https://raw.githubusercontent.com/graspgenx/graspgenx.github.io/main/static/videos/graspgen-x.mp4>
- Linked CVPR 2026 presentation: <https://www.youtube.com/watch?v=a2sv9EVQJXE>
- Paper and source archive: <https://arxiv.org/abs/2606.00998>
- Official code: <https://github.com/NVlabs/GraspGenX>
- Official Dex3 URDF/meshes used locally:
  `unitree_ros/robots/dexterous_hand_description/dex3_1/dex3_1_r.urdf`
- Official dimensioned Dex3-1 user manual:
  <https://marketing.unitree.com/article/zh/Dex3-1/User_Manual.html>

## Public-CAD audit

The detailed manufacturing CAD necessarily exists inside Unitree, but no
public release containing the two dorsal holes was found as of 2026-08-11:

- Unitree's official `unitree_ros` Dex3 directory contains only the left/right
  URDFs and per-link STL meshes. It contains no STEP, Parasolid, or native CAD.
- The current and historical `right_hand_palm_link.STL` revisions from
  `unitree_ros` and `xr_teleoperate` were inspected. The current mesh is copied
  byte-for-byte into the local GraspGen-X, G1Pilot, cuRobo, and simulation
  assets; none exposes the two dorsal threaded holes.
- Unitree's official `unitree_cad` repository contains A1, AlienGo, and Laikago
  STL files only—no G1 or Dex3.
- Unitree's current Hugging Face `unitree_model` archive contains G1 23-DoF and
  29-DoF USD packages, but no Dex3 directory or detailed hand CAD.
- A global GitHub code search found no public Dex3 STEP/STP file. GraspGen-X
  also ships the same simplified Unitree palm STL and does not publish its
  physical marker fixture.

Public source locations checked:

- <https://github.com/unitreerobotics/unitree_ros/tree/master/robots/dexterous_hand_description/dex3_1>
- <https://github.com/unitreerobotics/unitree_cad>
- <https://huggingface.co/datasets/unitreerobotics/unitree_model/tree/main/G1>
- <https://github.com/unitreerobotics/xr_teleoperate>

The manufacturing solid model was not released, but the official user manual
provides the missing dimensioned mounting-hole view. The palm STL remains the
source for the surrounding shell envelope, surface coordinate, and palm-link
frame.

The selected standalone `unitree_ros` URDF is the latest official Dex3-1 model
in the project. Its `right_hand_palm_link.STL` SHA-256 is
`86c0b231cc44477d64a6493e5a427ba16617a00738112dd187c652675b086fb9`,
byte-identical to the palm mesh used by the GraspGen-X cuRobo G1 model. All
seven right-hand joint origins and axes also match the cuRobo and
`xr_teleoperate` variants exactly; their URDF differences are joint limits,
materials, inertial orientation, and XR-only auxiliary links, none of which
changes this fixture geometry.

## Marker reconstruction

OpenCV's predefined-dictionary detector was run over the G1 sequence in the
linked presentation. The dorsal marker repeatedly decoded as ID 4 in the
6-by-6 family. For example, in the locally extracted 20-second G1 crop,
`DICT_6X6_50` returned these four corners:

```text
[[619, 937], [604, 950], [572, 937], [589, 925]]
```

The same wrist target decoded as ID 4 in the 22- and 24-second views. The
larger `DICT_6X6_100`, `250`, and `1000` dictionaries share their first marker
codes; `DICT_6X6_50` is the smallest compatible OpenCV family and matches the
project's observed ID range. A 40 mm active square plus a 5 mm white quiet zone
reconstructs the approximately 50 mm visible plate relative to the known
88 mm Dex3 hand width.

## Hole-pattern reconstruction

The supplied physical photograph was 696 x 928 pixels. Circle detection around
the two dorsal features returned representative outer-recess estimates:

```text
left  center ~= [225.5, 537.5] px, radius ~= 17.4 px
right center ~= [304.5, 546.5] px, radius ~= 15.2 px
center distance ~= 79.5 px
```

Registering the palm outline against the official 86.7 x 87.8 mm palm-envelope
dimensions gives approximately 5.2–5.4 pixels/mm in the local dorsal plane.
The resulting photograph estimates were:

```text
hole center spacing ~= 15.0–15.3 mm
inside opening ~= 3 mm
head recess ~= 5.5–6 mm
```

Direct caliper measurements on the real hand gave approximately 15.5 mm
center-to-center and an accurately measured 12.75 mm gap between the nearest
inner edges. The user directly inserted an M3 screw and confirmed the thread.

The official manual resolves the remaining ambiguity. Its mounting-hole drawing
calls out `2 x M3` to 3 mm depth, 15.00 mm center spacing, and locates the pair
centerline 66.70 mm from the wrist-side datum. The 15.5 mm caliper result was an
approximate check; the CAD default follows the explicit 15.00 mm dimension.

In the URDF, the palm mesh begins at the wrist datum at `x=0`, the finger-base
joints are at `x=77.7 mm`, and the mesh extends toward the fingers to
`x=86.7 mm`. The drawing's 66.70 mm wrist-to-hole dimension therefore maps
directly to palm `x=66.70 mm`. The holes straddle the drawing and URDF centerline
at palm `z=+/-7.50 mm`, so their midpoint is `[x,z]=[66.70,0] mm`.

## Palm surface and nominal pose

Ray intersections against the official `right_hand_palm_link.STL` show that the
dorsal shell under the plate is shallowly convex. Ray intersections at the
documented holes, palm `x=66.70 mm`, `z=+/-7.50 mm`, give `y=-21.330 mm` at
both positions. The first design incorrectly treated that support plane as
parallel to the palm-link `x-z` plane. A least-squares tangent fit over the M3
boss footprints gives `dy/dx=0.019947`, or 1.143 degrees. The first physical
print confirmed the consequence: its former 2.0 mm wrist pad remained clear
of the shell and the plate flexed.

The corrected design moves the third datum to plate `y=20 mm`, approximately
palm `x=31.69 mm`, where the official shell is `y=-20.958 mm`. Its center
height is 2.57 mm and its contact face is tilted by 1.994 degrees relative to
the plate to follow the local shell tangent. The nominal marker-center
translation is now approximately `[0.036816,-0.027427,0] m`; its orientation
also includes the 1.143-degree mounting pitch.

The plate's marker center is 30.0 mm wristward of the screw line. Its transform
is tied to the official hole drawing and the local surface tangent recovered
from the official palm mesh rather than an image-registration estimate.

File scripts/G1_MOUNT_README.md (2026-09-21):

# G1 V7 mount scripts

Start with [the CAD and printing guide](../artifacts/g1_mount_v7/README.md)
and [physical fit status](../artifacts/g1_mount_v7/FIT_STATUS.md). The F3D is
self-contained. STLs and the coupon 3MF are ready to open without running
Python. Geometry and M6 lengths remain subject to physical validation.

These scripts preserve the native Fusion build, checks and Bambu comparisons.
They locate the checkout from `__file__`; moving the checkout is supported.
Frozen carrier, shell, head, URDF and camera inputs are included under
`artifacts/g1_mount_v7/reference_inputs/`. The obsolete V6 frame generator has been removed; these are the current mount build scripts.

## Dependencies and execution

Local mesh/plot scripts require Python with numpy, trimesh, scipy, shapely,
rtree and matplotlib. Install these in your own environment; the original
vendored `python_packages` directory is deliberately omitted. The scripts
also work with these packages installed normally on Python's import path.
Fusion scripts additionally require Autodesk Fusion's `adsk` API and must
run inside Fusion. They expect the document named
`G1 V7 - broad crossbars and flat side plates`.

When invoking a script through Fusion MCP, load it with its real path so
`__file__` resolves correctly:

```python
from pathlib import Path

def run(_context):
    path = Path('/absolute/path/to/checkout/scripts/revise_g1_fit_coupons_r2_fusion.py')
    namespace = {'__file__': str(path), '__name__': 'g1_script'}
    exec(compile(path.read_text(encoding='utf-8'), str(path), 'exec'), namespace)
    namespace['run'](_context)
```

`build_g1_mount_v7_fusion.py` builds one requested part at a time through
`build('side_left')`, `build('side_right')`, `build('crossbar_upper')` and
`build('crossbar_lower')`. Start from a new empty document with the expected
name; existing component names are deliberately rejected. The coupon
builder also expects components to be absent. The R2 revision script is
idempotent for its named trim/marking features. Native scripts can alter the
active design; use the supplied archive or a separate document for review.

`validate_g1_mount_v7.py` writes centered print STLs and checks complete
geometry/access/target rays. `check_g1_mount_v7_board_contact.py` checks the
four carrier contacts. `validate_g1_coupons_r2.py` compares revised coupons
with the included pre-R2 and precision meshes; the pre-R2 STLs in
`original_reference/` are comparison inputs, not current print files.

`slice_g1_coupons_r2.py` requires Bambu Studio at its standard Windows path.
The comparison profiles are included under
`artifacts/g1_print_time/controlled_comparison/`. It slices both revisions;
the included R2 3MF is already sliced. `estimate_g1_print_time.py --quick-check` regenerates the limited side-plate comparison using locally
installed Bambu profiles; it is not a complete structural print study.

Run `package_g1_coupons_r2.py` then `package_g1_mount_v7.py` to refresh the
ZIPs. They include file hashes and verify ZIP integrity. The ZIP `source/`
files are provenance copies, not a separate runnable directory layout.

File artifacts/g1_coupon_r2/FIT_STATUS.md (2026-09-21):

# Physical fit status — recorded 2026-09-13

These observations were reported by the user during the design conversation;
they are not instrumented measurements or a completed acceptance test.

| Item | Latest evidence | Remaining check |
| --- | --- | --- |
| Original V6 frame | Small M6 boss broke during support removal/handling in PLA. | Replaced by the V7 broad crossbar architecture. |
| Upper R2 coupons | User reports M6 x 25 worked with the top coupons. | Washer use/thickness, turns from first engagement to clamping, seating and usable thread depth were not recorded. Keep 25 mm as the upper length under test. |
| Lower R2 coupons | M6 x 25 does not engage through the coupons; it threads into the robot with the coupon removed. | Measure screw reach, seating/alignment, usable thread depth and bottom clearance; lower screw length is unresolved. |
| Bare-screw comparison | About six exposed threads at the lower shell and twelve at the upper shell when first engaging. | Approximate thread counts, not caliper measurements. They suggest different recess depths but do not establish final bolt lengths. |
| Full V7 assembly | CAD/mesh checks passed. | Physical assembly, stiffness, creep, board flatness, reinstall repeatability and calibration accuracy have not been established. |

The old four-M6-x-20 hardware assumption is superseded. Upper M6 x 35 and
lower M6 x 40 were discussed as rough trial estimates; neither is a verified
specification. The later report that 25 mm works for the upper coupons takes
precedence over the rough upper estimate. Do not order or install 35/40 mm
as a confirmed bill of materials based on this handoff.

The screw head and washer must clamp the printed part before the tip or
thread runout contacts an internal stop. Threading a bare screw fully in
does not establish the usable threaded depth with the mount installed.

All four current coupons and crossbars retain the same nominal **12 mm
shell-to-washer-face stack at the screw axis**. A deeper lower washer/head
recess was discussed but has not been modeled, exported, structurally
validated or printed. No 6 mm or 8 mm seat is a released variant. A future
coupon must match the final structural washer-seat position.

The frame still requires **eight M5 x 30 screws**, eight approximately 1 mm
flat washers and eight standard M5 hex nuts. An M5 x 20 alternative was
discussed and not implemented. The accepted carrier still uses four M4 x 30
screws, eight M4 washers and four M4 nyloc nuts.

Next physical check: record the washer dimensions and the upper engagement
turns; measure the lower head-to-shell gap at first engagement and usable
threaded depth. Resolve the lower hardware or a matching structural recess
before printing the full mount. The initial accuracy/repeatability targets
in the design README remain targets, not achieved specifications.

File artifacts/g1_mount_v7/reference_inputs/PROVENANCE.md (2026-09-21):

# Input provenance

- Source repository: https://github.com/sri299792458/robot-calibration-aprilcube-prototype
- Source branch at handoff: `feature/dex3-aruco-calibration`
- Source fixture commit: `b555c3adea33966607c26837264230dbc1208c6c`
- Carrier mesh bytes are retained from that commit. The manifest is reduced
  to the carrier definition and frozen mount inputs, without the old frame.
- Camera layout source: https://github.com/sri299792458/g1-dex3-tabletop
- Camera source commit: `a26cf3752a54e1aa7f42398e48a0b5e230bbda41`
- Measured camera bundle: `dex3_shared_20260812_selected_free`
- Bundle SHA-256: `dae03341c35f7844cfb43cfee0a92386f2c508d26fa081f6683fb19ece99a2f3`
- Camera serial: `348522074178`

Robot model references are from the supplied handoff's Unitree ROS model;
the upstream license is preserved in `robot_model/UNITREE_ROS_LICENSE`.
The current frame geometry is the V7 native Fusion redesign.

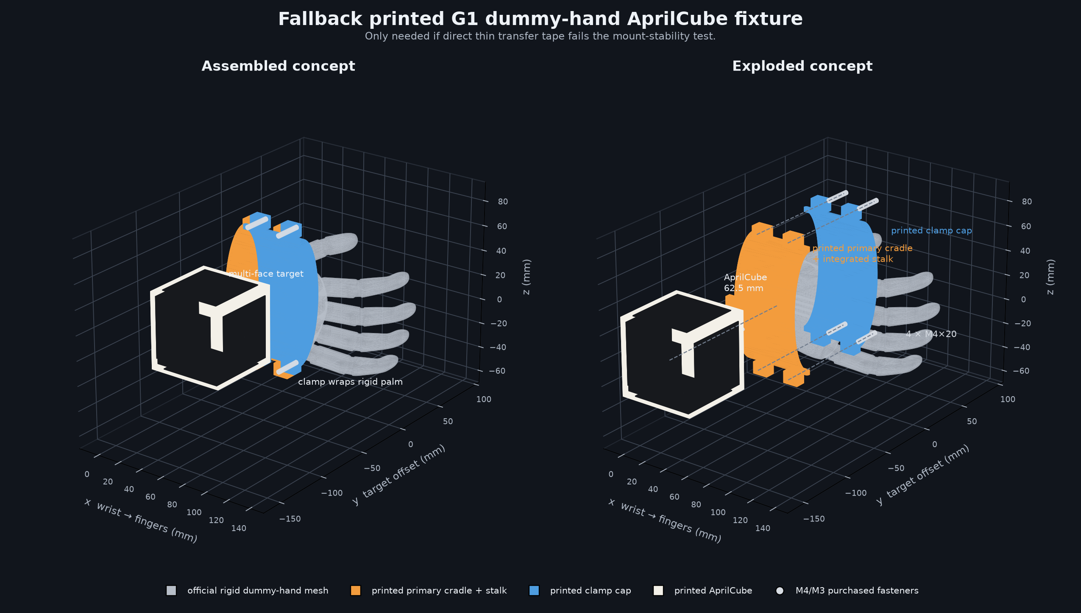
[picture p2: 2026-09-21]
renders/dummy_hand_aprilcube_mount_concept.png

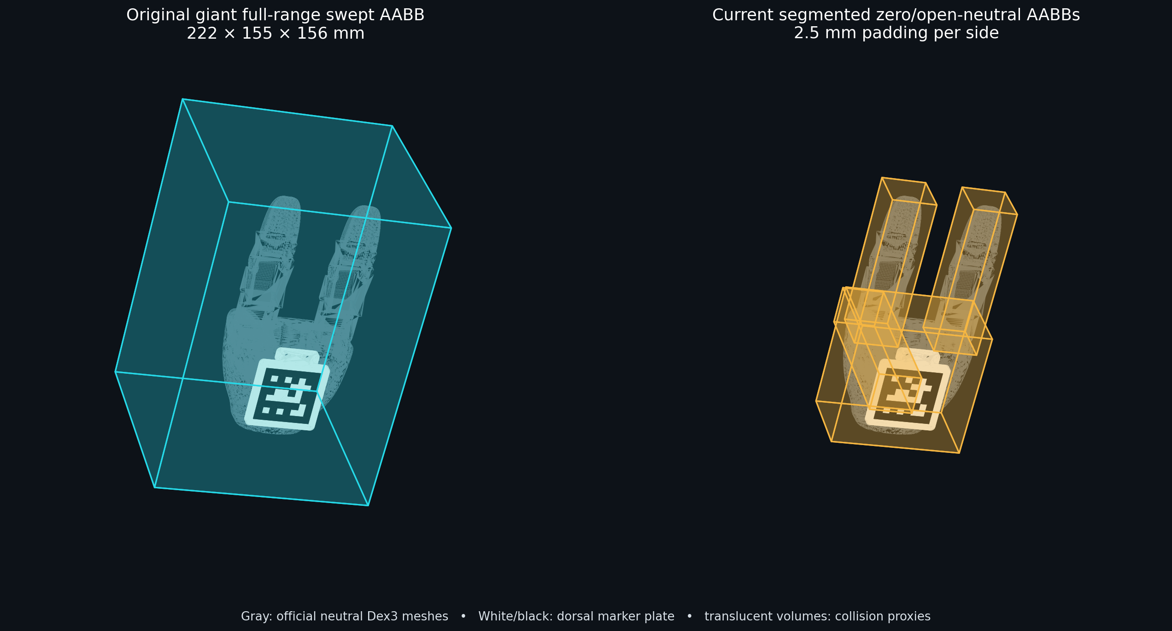
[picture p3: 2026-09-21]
renders/dex3_collision_envelope_comparison.png

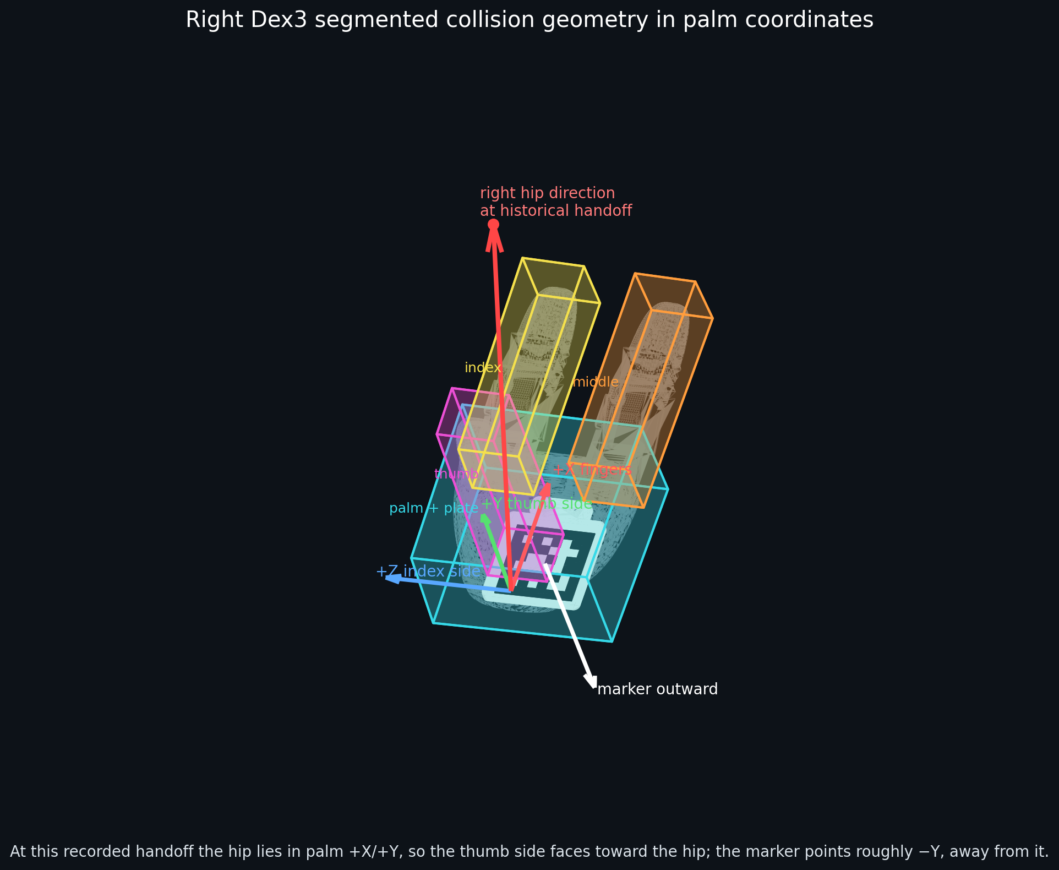
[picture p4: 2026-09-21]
renders/dex3_segmented_box_placement.png

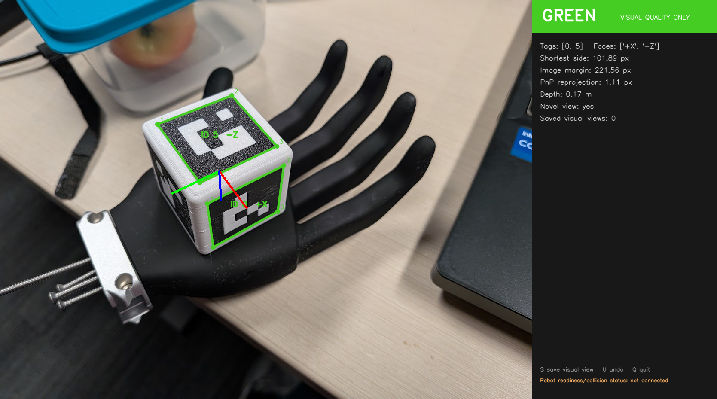
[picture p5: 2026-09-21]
renders/aprilcube_quality_preview.png

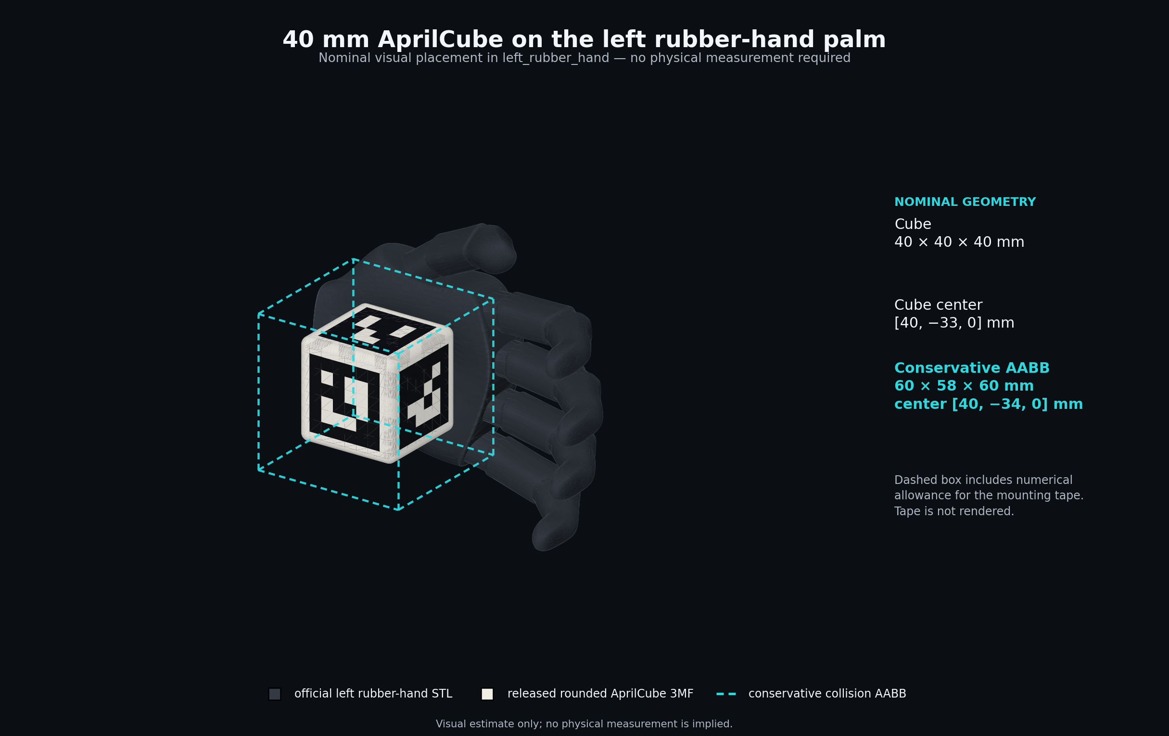
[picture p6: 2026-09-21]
renders/left_palm_aprilcube_envelope.png

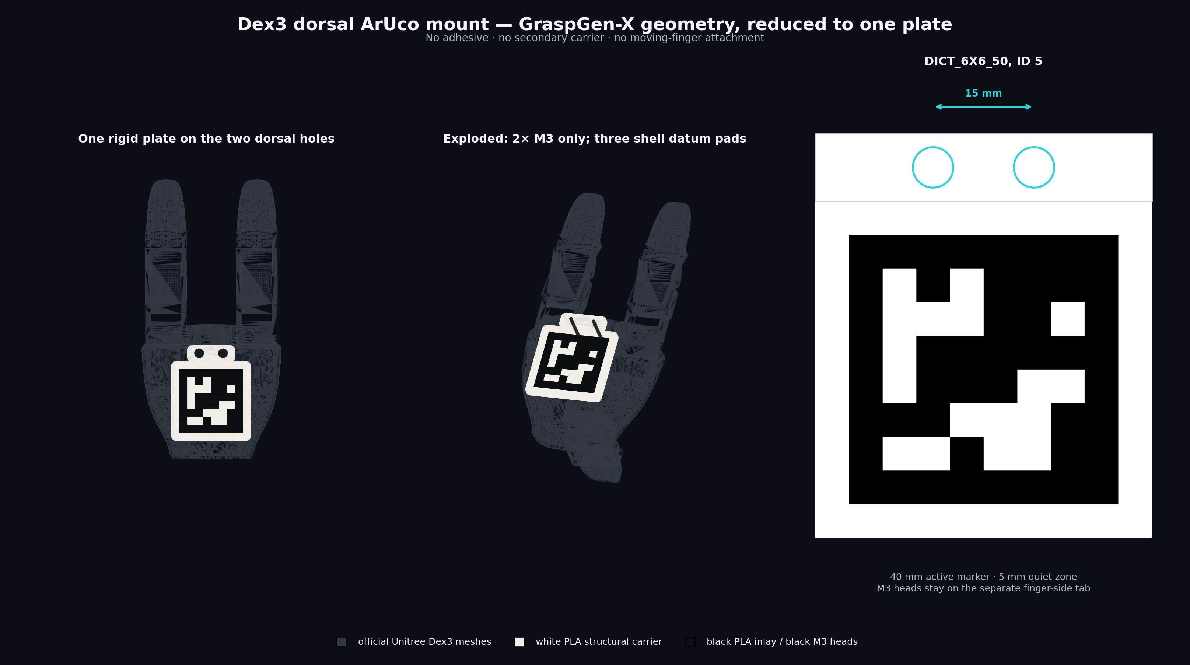
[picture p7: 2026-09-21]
renders/dex3_dorsal_aruco_mount_id5.png

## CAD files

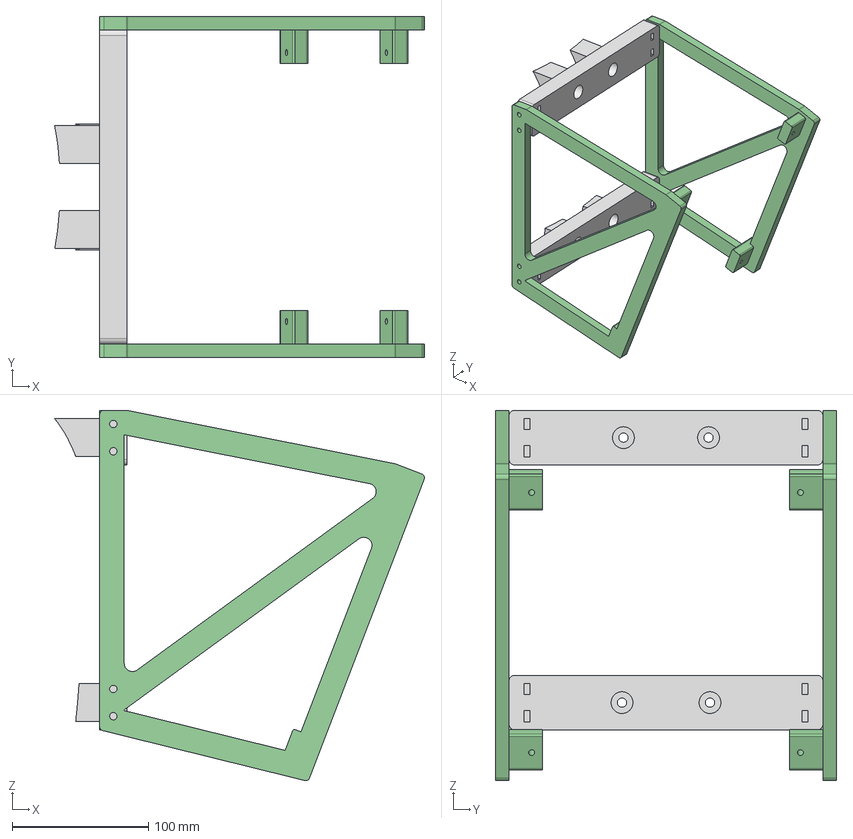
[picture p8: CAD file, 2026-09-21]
artifacts/g1_mount_v7/cad/G1_calibration_mount_assembly.step
271.2 x 250.0 x 271.4 mm

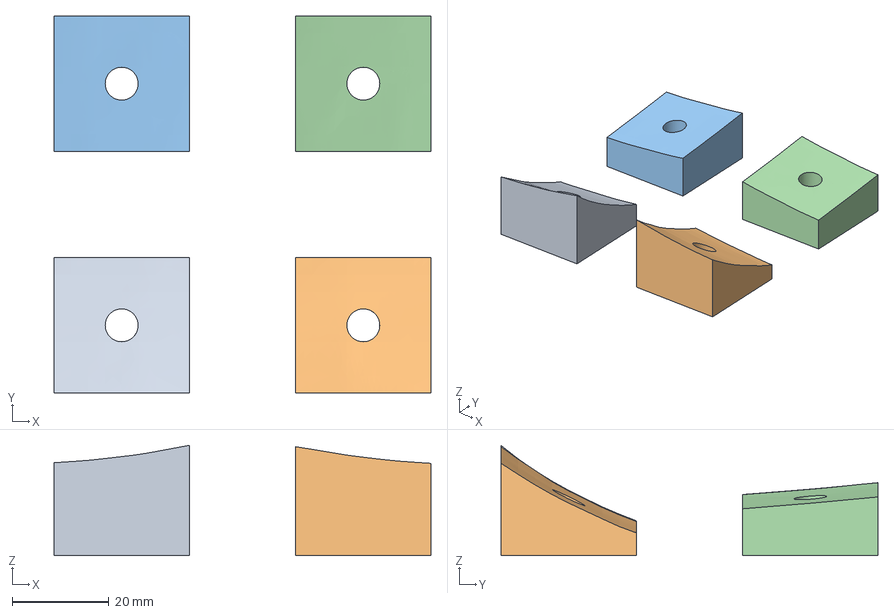
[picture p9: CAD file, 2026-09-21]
artifacts/g1_coupon_r2/G1_R2_fit_coupons.3mf
78.0 x 78.0 x 22.8 mm
FIT_R2_upper_left.stl
FIT_R2_upper_right.stl
FIT_R2_lower_left.stl
FIT_R2_lower_right.stl

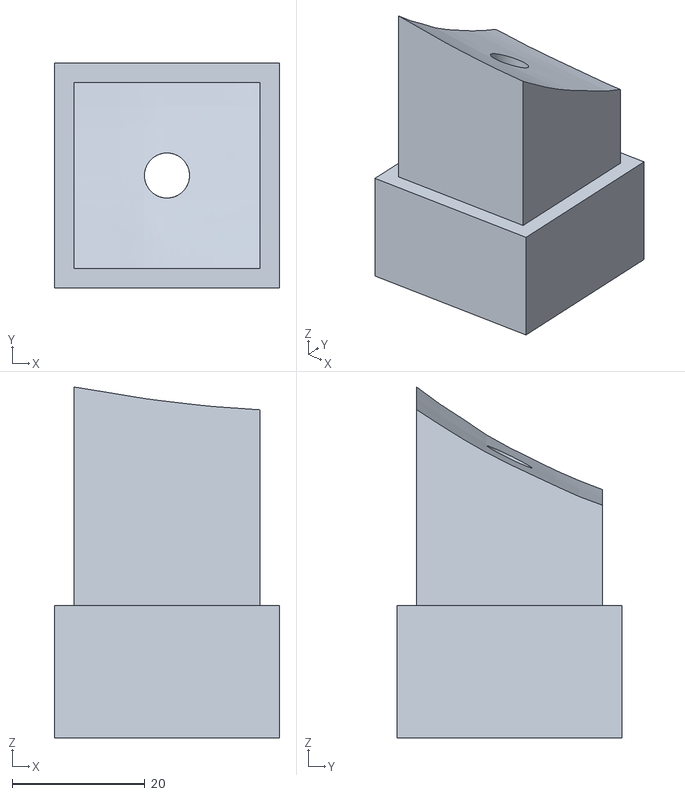
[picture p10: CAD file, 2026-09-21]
artifacts/g1_coupon_r2/original_reference/FIT_ONLY_upper_right_PRINT.stl
34.0 x 34.0 x 53.0

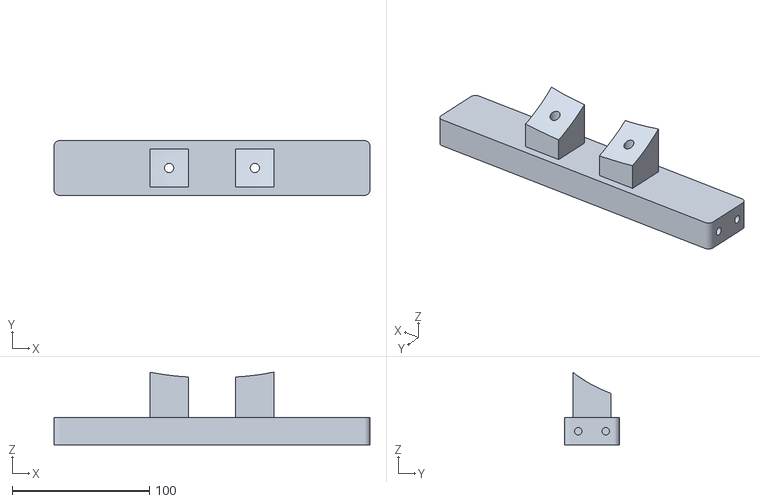
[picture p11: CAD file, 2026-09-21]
artifacts/g1_coupon_r2/precision_reference/V7_crossbar_upper.stl
230.0 x 40.0 x 53.1

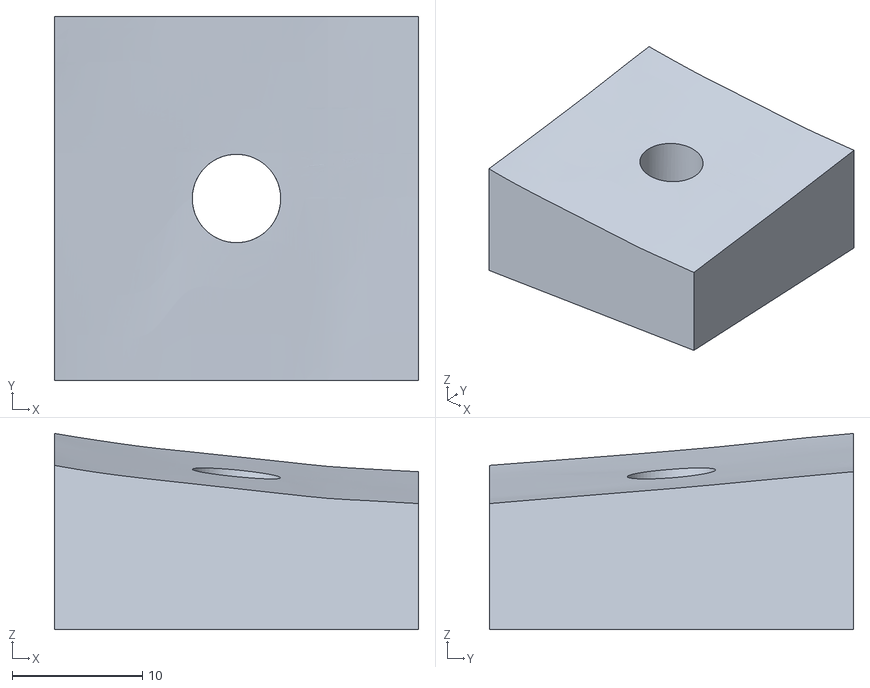
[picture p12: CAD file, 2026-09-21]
artifacts/g1_coupon_r2/print_parts/FIT_R2_lower_right_PRINT.stl
28.0 x 28.0 x 15.1

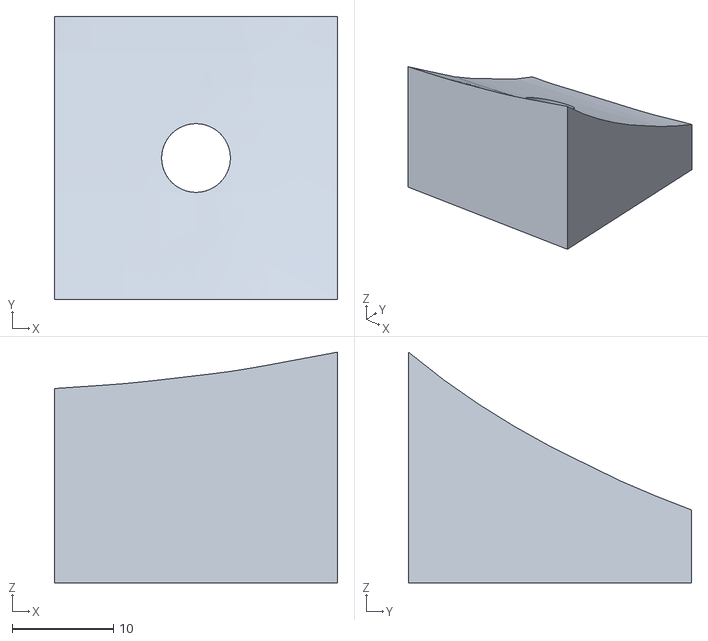
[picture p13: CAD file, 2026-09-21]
artifacts/g1_mount_v7/cad/FIT_ONLY_upper_left_PRINT.stl
28.0 x 28.0 x 22.8

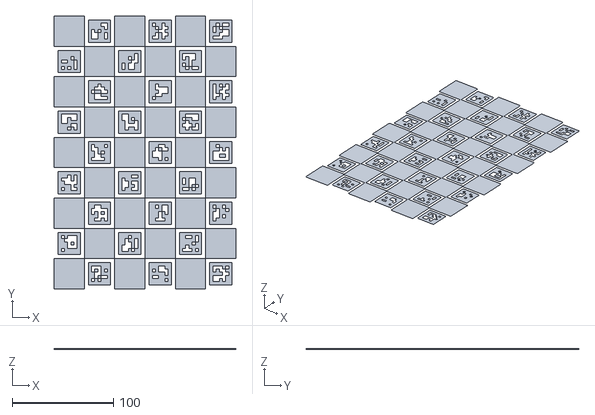
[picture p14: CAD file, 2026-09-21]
artifacts/g1_mount_v7/reference_inputs/current_design/cad/carrier_black_inlay.stl
180.0 x 270.0 x 0.6

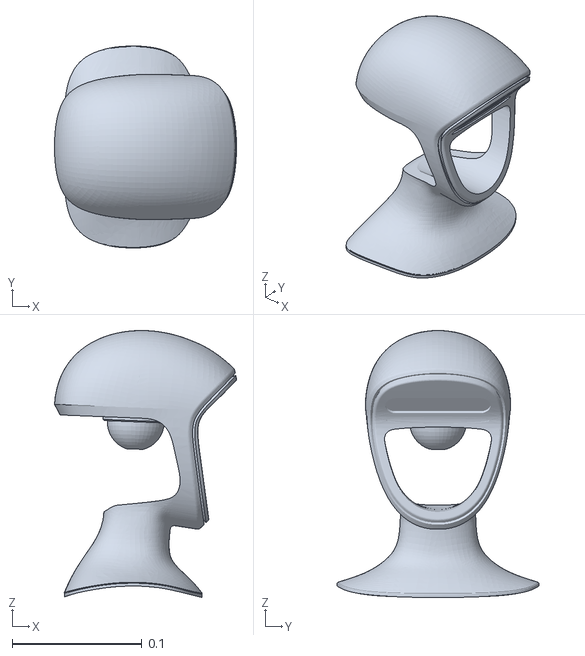
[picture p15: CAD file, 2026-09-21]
artifacts/g1_mount_v7/reference_inputs/robot_model/head_link.STL
0.14 x 0.156 x 0.206

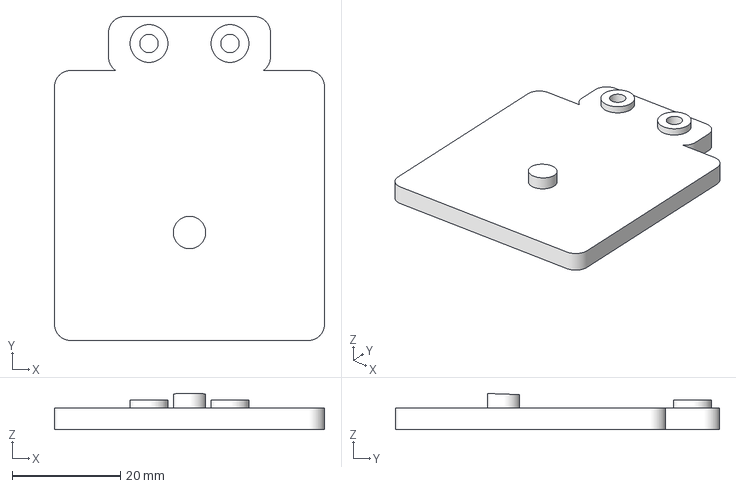
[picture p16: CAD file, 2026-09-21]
cad/dex3_dorsal_aruco_mount_id5/dex3_dorsal_aruco_mount_multicolor_h2d.3mf
50.0 x 60.0 x 6.67 mm

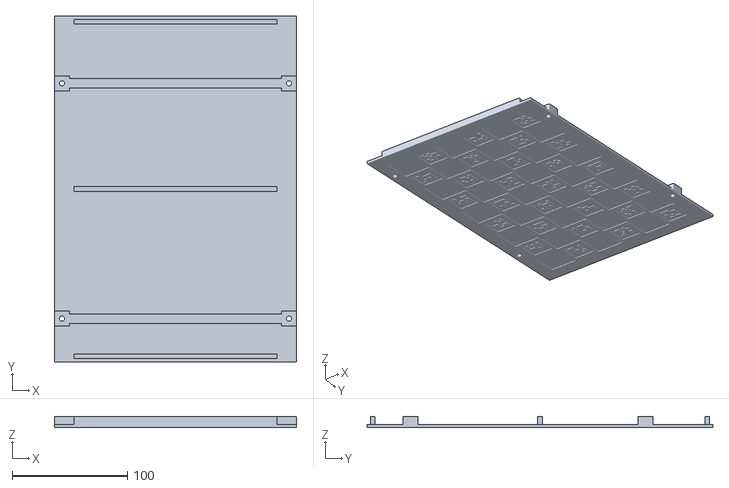
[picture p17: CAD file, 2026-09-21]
cad/torso_charuco_fixture/carrier_white_body.stl
210.0 x 300.0 x 9.40

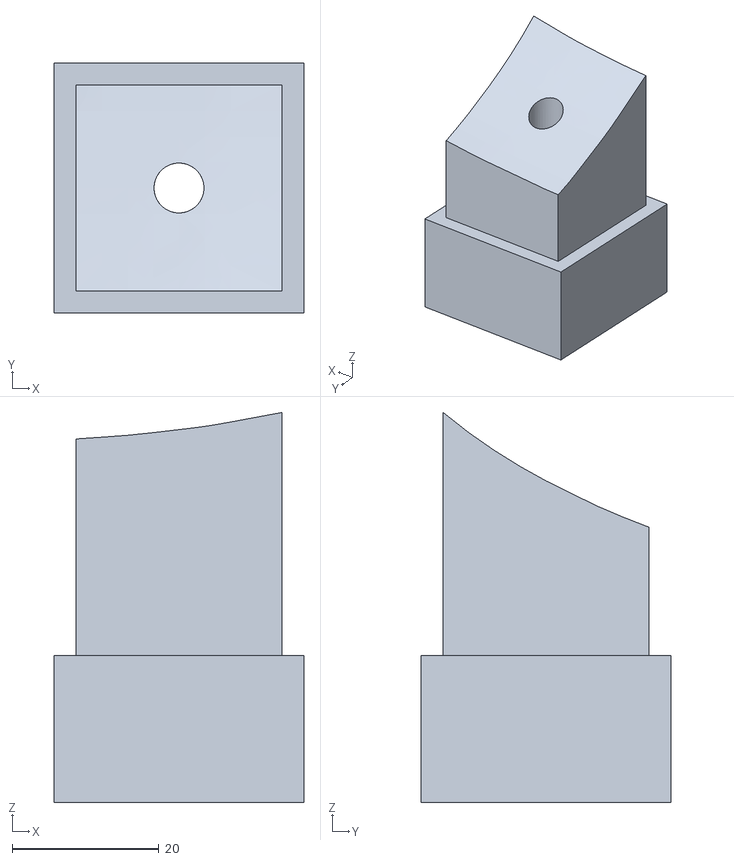
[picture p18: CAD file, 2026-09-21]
artifacts/g1_coupon_r2/original_reference/FIT_ONLY_upper_left_PRINT.stl
34.0 x 34.0 x 53.1

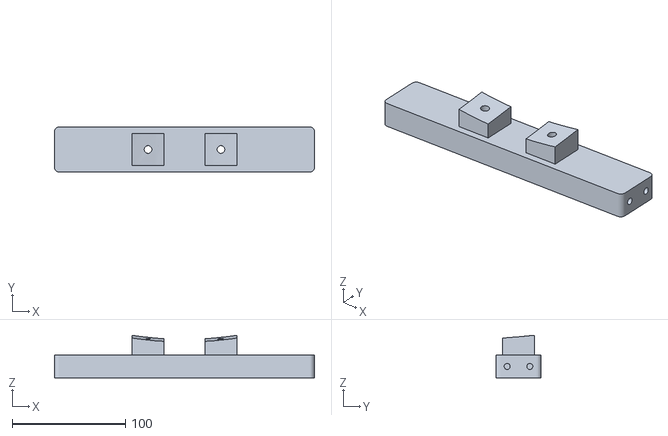
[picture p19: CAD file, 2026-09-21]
artifacts/g1_coupon_r2/precision_reference/V7_crossbar_lower.stl
230.0 x 40.0 x 37.6

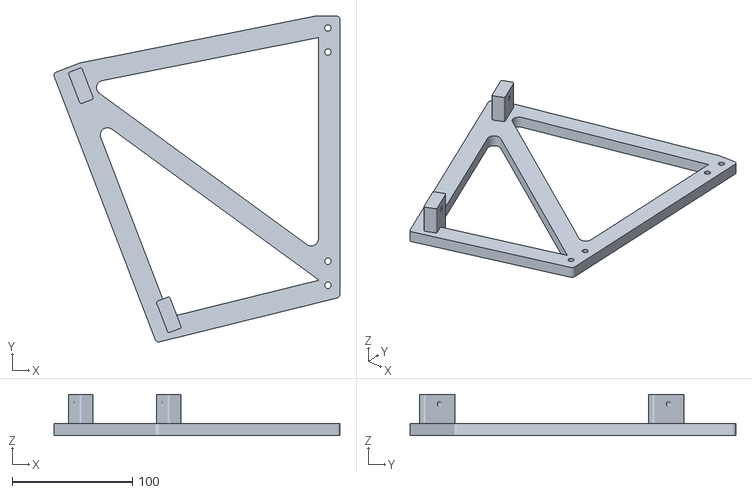
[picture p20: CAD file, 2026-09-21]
artifacts/g1_mount_v7/cad/V7_side_right_PRINT.stl
238.1 x 271.4 x 34.5

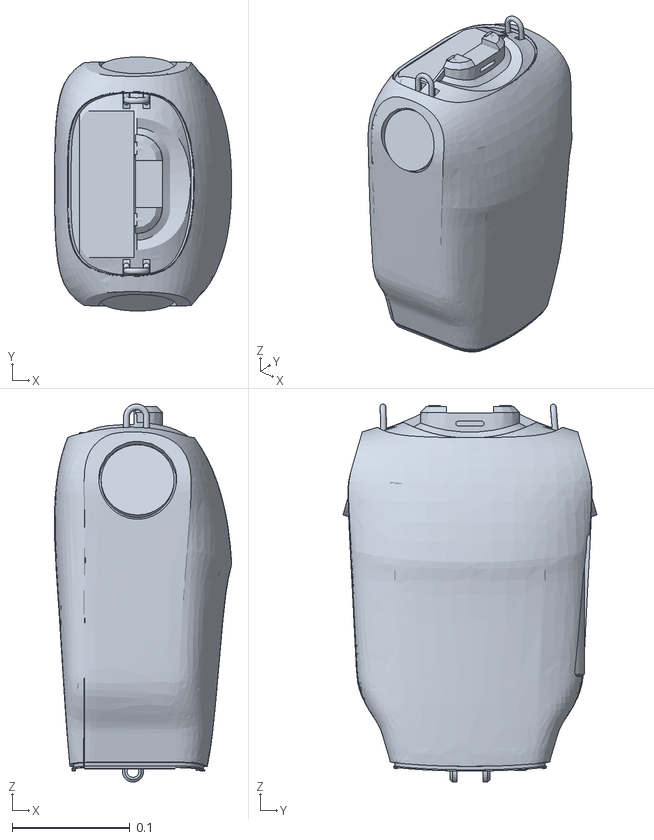
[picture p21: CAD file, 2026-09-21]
artifacts/g1_mount_v7/reference_inputs/robot_model/torso_link_rev_1_0.STL
0.15 x 0.215 x 0.321

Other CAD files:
artifacts/g1_coupon_r2/print_parts/FIT_R2_lower_left_PRINT.stl
artifacts/g1_mount_v7/fit_coupons/FIT_ONLY_upper_left_PRINT.stl
artifacts/g1_coupon_r2/original_reference/FIT_ONLY_lower_left_PRINT.stl
artifacts/g1_coupon_r2/original_reference/FIT_ONLY_lower_right_PRINT.stl
artifacts/g1_coupon_r2/print_parts/FIT_R2_upper_left_PRINT.stl
artifacts/g1_coupon_r2/print_parts/FIT_R2_upper_right_PRINT.stl
artifacts/g1_mount_v7/cad/FIT_ONLY_lower_left_PRINT.stl
artifacts/g1_mount_v7/cad/FIT_ONLY_lower_right_PRINT.stl
artifacts/g1_mount_v7/cad/FIT_ONLY_upper_right_PRINT.stl
artifacts/g1_mount_v7/cad/G1_calibration_mount_native.f3d
artifacts/g1_mount_v7/cad/V7_crossbar_lower_PRINT.stl
artifacts/g1_mount_v7/cad/V7_crossbar_upper_PRINT.stl
artifacts/g1_mount_v7/cad/V7_side_left_PRINT.stl
artifacts/g1_mount_v7/fit_coupons/FIT_ONLY_lower_left_PRINT.stl
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

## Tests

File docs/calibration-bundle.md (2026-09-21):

# Using the selected calibration bundle

The bundle is a portable description of the selected August 12 calibration.
It records camera and target transforms, seven joint-position offsets, input
identities and fit diagnostics. Loading it does not fit another model or contact
the robot.

```mermaid
flowchart LR
  accTitle: Read and apply a calibration bundle offline
  accDescr: The bundle content hash is checked when loaded. Materialization additionally checks the original URDF hash and writes a separate calibrated URDF while retaining measured joint coordinates.
  B["Bundle JSON"] --> H["Verify content hash"]
  U["Original URDF"] --> V["Verify base URDF hash"]
  H --> V
  V --> O["Separate calibrated URDF"]
```

| Operation | Code |
| --- | --- |
| Validate fields and content hash | `CalibrationBundle.load` / `from_dict` in [`calibration_bundle.py`](../src/g1_aprilcube_calibration/calibration_bundle.py) |
| Apply the camera and joint offsets | `CalibrationBundle.materialize_urdf` in the same file |
| Expose read-only inspection and optional export | `inspect-calibration-bundle` in [`workflow_cli.py`](../src/g1_aprilcube_calibration/workflow_cli.py) |
| Check equivalence, tampering and preservation of the base model | [`test_calibration_bundle.py`](../tests/test_calibration_bundle.py) |

## Inspect without exporting

From the repository root:

```bash
.venv/bin/g1-calib inspect-calibration-bundle \
  --calibration-bundle config/calibrations/dex3_shared_20260812_selected_free.json \
  --urdf config/urdf/g1_29dof_rev_1_0_g1pilot_collision.urdf
```

The command reports the bundle identity, transforms, offsets and validation
record. Add `--output-urdf work/calibrated.urdf` to write an overlay. The output
must differ from the base URDF, and the base file must match the bundle hash.
Relative mesh paths are rebased for the output location. Keep the Unitree model
checkout available when loading meshes.

Joint offsets are incorporated into the copied model's joint origins. Continue
to provide measured encoder positions to that model; adding the offsets to the
positions as well would apply them twice. This command does not change a robot
controller's active model.

## Interpreting the evidence

The selected fit used 41 left and 62 right observations. The paths in
`provenance.datasets` identify those original inputs and retain their content
hashes. **They are not required to inspect or materialize this bundle.** Raw
sessions and analysis outputs remain separate local evidence.

The bundle's validation status remains
`analysis_candidate_not_physical_task_validation`, preserving what was recorded
when it was created. The August 25 stacking baseline subsequently used this
bundle. A successful demonstration does not establish absolute calibration
accuracy across the workspace or on a different installation.

The camera/head configuration must match the calibration. Fitted target
transforms are effective registrations for that model; the physical wrist CAD
remains the reference for visibility and occlusion. The later V7 torso fixture
does not replace this bundle and has not produced a qualified replacement
calibration.

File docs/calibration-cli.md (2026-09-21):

# Calibration implementation entry points

This reference locates the retained calibration pipeline. Start with the
[research guide's workflow](https://sri299792458.github.io/g1-research-docs/calibration/workflow.html)
and [results](https://sri299792458.github.io/g1-research-docs/calibration/results.html)
for the lessons from physical collection and model evaluation. The later
tabletop bilateral workflow is a separate implementation.

```mermaid
flowchart TD
  accTitle: Recorded observations to a native calibration result
  accDescr: A retained capture session is rebuilt into a dataset, split by pose, and fitted with the pinned native Ceres backend. Independent evaluation retains training and held-out residuals.
  S["Session: images, camera info,<br/>measured state and hashes"] --> D["DatasetBuilder"]
  D --> T["Pose-level training / holdout split"]
  T --> N["robot_calibration bridge<br/>native Ceres fit"]
  N --> E["NativeCalibrationProjection<br/>evaluate fixed fit"]
  E --> R["Results, residuals and provenance"]
```

| Responsibility | Source |
| --- | --- |
| CLI parser and command dispatch | [`cli.py`](../src/g1_aprilcube_calibration/cli.py), [`workflow_cli.py`](../src/g1_aprilcube_calibration/workflow_cli.py) |
| Capture ownership and hardware entry points | [`hardware_cli.py`](../src/g1_aprilcube_calibration/hardware_cli.py) |
| Retained session and image/state pairing | [`session_store.py`](../src/g1_aprilcube_calibration/session_store.py), [`timestamp_pairing.py`](../src/g1_aprilcube_calibration/timestamp_pairing.py) |
| Rebuild and split observations | [`dataset_builder.py`](../src/g1_aprilcube_calibration/dataset_builder.py) |
| Native optimizer adapter | [`robot_calibration_bridge.py`](../src/g1_aprilcube_calibration/robot_calibration_bridge.py) |
| Evaluate native results and export residuals | [`calibration_evaluation.py`](../src/g1_aprilcube_calibration/calibration_evaluation.py), [`residual_report.py`](../src/g1_aprilcube_calibration/residual_report.py) |
| Compare bilateral models offline | [`analyze_dual_arm_native.py`](../tools/analyze_dual_arm_native.py), [`analyze_native_joint_subsets.py`](../tools/analyze_native_joint_subsets.py) |
| Study dataset size and residual structure | [`analyze_native_learning_curve.py`](../tools/analyze_native_learning_curve.py), [`analyze_residual_predictability.py`](../tools/analyze_residual_predictability.py), [`analyze_calibration_diagnostics.py`](../tools/analyze_calibration_diagnostics.py) |

## Offline command discovery

After setup, these commands display interfaces without collecting data or
invoking a fit:

```bash
.venv/bin/g1-calib --help
.venv/bin/g1-calib build-dataset --help
.venv/bin/g1-calib solve --help
.venv/bin/python tools/analyze_dual_arm_native.py --help
```

`build-dataset` consumes a retained session, verifies the recorded artifacts and
pairing, and writes a derived dataset. An unfinished session requires explicit
`--allow-unfinalized`; that flag does not certify successful session cleanup.
The clean source tree does not include the raw sessions.

`solve` uses the pinned Mike Ferguson `robot_calibration` Ceres backend. The
Python projection/evaluation code does not provide a second optimizer. The
native runner and dependencies are recorded in
[`config/upstream_pins.yaml`](../config/upstream_pins.yaml) and
[`tools/install_robot_calibration_local.sh`](../tools/install_robot_calibration_local.sh).
Installing or rebuilding that runtime is separate from reading this code.

The fixed-target and free-target hypotheses answer different questions. A free
registration can absorb kinematic error; a small training residual alone does
not establish the physical camera pose. Keep pose-level holdout results, side
identity, marker geometry and the fitted model together.

## Hardware boundary

The right default pairs `hardware_dex3_aruco.yaml` with
`dex3_dorsal_aruco_target.json` (ID 4). The left pairs
`hardware_dex3_left_aruco_id5.yaml` with
`dex3_left_dorsal_aruco_id5_target.json` (ID 5). Hardware, target and collision
profiles are under `config/` and must match the actual installation.

Hardware wrappers require the commissioned PC2 watchdog, the correct ROS/SDK
environment, camera profile and Ethernet interface. They can acquire ownership
and move the robot. Fixture inspection, offline tests and repository
consolidation do not authorize those actions. For the distinct motion service,
FSM and machine-layout meanings, read the retained
[control and recovery evidence](g1_control_state_and_recovery.md).

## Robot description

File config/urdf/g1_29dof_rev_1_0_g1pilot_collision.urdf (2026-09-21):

<?xml version='1.0' encoding='utf-8'?>
<robot name="g1_29dof_rev_1_0">
  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
  <mujoco>
    <compiler meshdir="meshes" discardvisual="false" />
  </mujoco>
  <link name="pelvis">
    <inertial>
      <origin xyz="0 0 -0.07605" rpy="0 0 0" />
      <mass value="3.813" />
      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
    </inertial>
    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
  </link>
  <link name="pelvis_contour_link">
    <inertial>
      <origin xyz="0 0 0" rpy="0 0 0" />
      <mass value="0.001" />
      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
    </inertial>
    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
  </link>
  <joint name="pelvis_contour_joint" type="fixed">
    <parent link="pelvis" />
    <child link="pelvis_contour_link" />
  </joint>
  <link name="left_hip_pitch_link">
    <inertial>
      <origin xyz="0.002741 0.047791 -0.02606" rpy="0 0 0" />
      <mass value="1.35" />
      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
    </inertial>
    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
  </link>
  <joint name="left_hip_pitch_joint" type="revolute">
    <origin xyz="0 0.064452 -0.1027" rpy="0 0 0" />
    <parent link="pelvis" />
    <child link="left_hip_pitch_link" />
    <axis xyz="0 1 0" />
    <limit lower="-2.5307" upper="2.8798" effort="88" velocity="32" />
  </joint>
  <link name="left_hip_roll_link">
    <inertial>
      <origin xyz="0.029812 -0.001045 -0.087934" rpy="0 0 0" />
      <mass value="1.52" />
      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
    </inertial>
    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
  </link>
  <joint name="left_hip_roll_joint" type="revolute">
    <origin xyz="0 0.052 -0.030465" rpy="0 -0.1749 0" />
    <parent link="left_hip_pitch_link" />
    <child link="left_hip_roll_link" />
    <axis xyz="1 0 0" />
    <limit lower="-0.5236" upper="2.9671" effort="139" velocity="20" />
  </joint>
  <link name="left_hip_yaw_link">
    <inertial>
      <origin xyz="-0.057709 -0.010981 -0.15078" rpy="0 0 0" />
      <mass value="1.702" />
      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
    </inertial>
    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
  </link>
  <joint name="left_hip_yaw_joint" type="revolute">
    <origin xyz="0.025001 0 -0.12412" rpy="0 0 0" />
    <parent link="left_hip_roll_link" />
    <child link="left_hip_yaw_link" />
    <axis xyz="0 0 1" />
    <limit lower="-2.7576" upper="2.7576" effort="88" velocity="32" />
  </joint>
  <link name="left_knee_link">
    <inertial>
      <origin xyz="0.005457 0.003964 -0.12074" rpy="0 0 0" />
      <mass value="1.932" />
      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
    </inertial>
    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
  </link>
  <joint name="left_knee_joint" type="revolute">
    <origin xyz="-0.078273 0.0021489 -0.17734" rpy="0 0.1749 0" />
    <parent link="left_hip_yaw_link" />
    <child link="left_knee_link" />
    <axis xyz="0 1 0" />
    <limit lower="-0.087267" upper="2.8798" effort="139" velocity="20" />
  </joint>
  <link name="left_ankle_pitch_link">
    <inertial>
      <origin xyz="-0.007269 0 0.011137" rpy="0 0 0" />
      <mass value="0.074" />
      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
    </inertial>
    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
  </link>
  <joint name="left_ankle_pitch_joint" type="revolute">
    <origin xyz="0 -9.4445E-05 -0.30001" rpy="0 0 0" />
    <parent link="left_knee_link" />
    <child link="left_ankle_pitch_link" />
    <axis xyz="0 1 0" />
    <limit lower="-0.87267" upper="0.5236" effort="35" velocity="30" />
  </joint>
  <link name="left_ankle_roll_link">
    <inertial>
      <origin xyz="0.026505 0 -0.016425" rpy="0 0 0" />
      <mass value="0.608" />
      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
    </inertial>
    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
  </link>
  <joint name="left_ankle_roll_joint" type="revolute">
    <origin xyz="0 0 -0.017558" rpy="0 0 0" />
    <parent link="left_ankle_pitch_link" />
    <child link="left_ankle_roll_link" />
    <axis xyz="1 0 0" />
    <limit lower="-0.2618" upper="0.2618" effort="35" velocity="30" />
  </joint>
  <link name="right_hip_pitch_link">
    <inertial>
      <origin xyz="0.002741 -0.047791 -0.02606" rpy="0 0 0" />
      <mass value="1.35" />
      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
    </inertial>
    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
  </link>
  <joint name="right_hip_pitch_joint" type="revolute">
    <origin xyz="0 -0.064452 -0.1027" rpy="0 0 0" />
    <parent link="pelvis" />
    <child link="right_hip_pitch_link" />
    <axis xyz="0 1 0" />
    <limit lower="-2.5307" upper="2.8798" effort="88" velocity="32" />
  </joint>
  <link name="right_hip_roll_link">
    <inertial>
      <origin xyz="0.029812 0.001045 -0.087934" rpy="0 0 0" />
      <mass value="1.52" />
      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
    </inertial>
    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
  </link>
  <joint name="right_hip_roll_joint" type="revolute">
    <origin xyz="0 -0.052 -0.030465" rpy="0 -0.1749 0" />
    <parent link="right_hip_pitch_link" />
    <child link="right_hip_roll_link" />
    <axis xyz="1 0 0" />
    <limit lower="-2.9671" upper="0.5236" effort="139" velocity="20" />
  </joint>
  <link name="right_hip_yaw_link">
    <inertial>
      <origin xyz="-0.057709 0.010981 -0.15078" rpy="0 0 0" />
      <mass value="1.702" />
      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
    </inertial>
    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
  </link>
  <joint name="right_hip_yaw_joint" type="revolute">
    <origin xyz="0.025001 0 -0.12412" rpy="0 0 0" />
    <parent link="right_hip_roll_link" />
    <child link="right_hip_yaw_link" />
    <axis xyz="0 0 1" />
    <limit lower="-2.7576" upper="2.7576" effort="88" velocity="32" />
  </joint>
  <link name="right_knee_link">
    <inertial>
      <origin xyz="0.005457 -0.003964 -0.12074" rpy="0 0 0" />
      <mass value="1.932" />
      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
    </inertial>
    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
  </link>
  <joint name="right_knee_joint" type="revolute">
    <origin xyz="-0.078273 -0.0021489 -0.17734" rpy="0 0.1749 0" />
    <parent link="right_hip_yaw_link" />
    <child link="right_knee_link" />
    <axis xyz="0 1 0" />
    <limit lower="-0.087267" upper="2.8798" effort="139" velocity="20" />
  </joint>
  <link name="right_ankle_pitch_link">
    <inertial>
      <origin xyz="-0.007269 0 0.011137" rpy="0 0 0" />
      <mass value="0.074" />
      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
    </inertial>
    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
  </link>
  <joint name="right_ankle_pitch_joint" type="revolute">
    <origin xyz="0 9.4445E-05 -0.30001" rpy="0 0 0" />
    <parent link="right_knee_link" />
    <child link="right_ankle_pitch_link" />
    <axis xyz="0 1 0" />
    <limit lower="-0.87267" upper="0.5236" effort="35" velocity="30" />
  </joint>
  <link name="right_ankle_roll_link">
    <inertial>
      <origin xyz="0.026505 0 -0.016425" rpy="0 0 0" />
      <mass value="0.608" />
      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
    </inertial>
    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
  </link>
  <joint name="right_ankle_roll_joint" type="revolute">
    <origin xyz="0 0 -0.017558" rpy="0 0 0" />
    <parent link="right_ankle_pitch_link" />
    <child link="right_ankle_roll_link" />
    <axis xyz="1 0 0" />
    <limit lower="-0.2618" upper="0.2618" effort="35" velocity="30" />
  </joint>
  <link name="waist_yaw_link">
    <inertial>
      <origin xyz="0.003494 0.000233 0.018034" rpy="0 0 0" />
      <mass value="0.214" />
      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
    </inertial>
    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
  </link>
  <joint name="waist_yaw_joint" type="revolute">
    <origin xyz="0 0 0" rpy="0 0 0" />
    <parent link="pelvis" />
    <child link="waist_yaw_link" />
    <axis xyz="0 0 1" />
    <limit lower="-2.618" upper="2.618" effort="88" velocity="32" />
  </joint>
  <link name="waist_roll_link">
    <inertial>
      <origin xyz="0 2.3E-05 0" rpy="0 0 0" />
      <mass value="0.086" />
      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
    </inertial>
    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
  </link>
  <joint name="waist_roll_joint" type="revolute">
    <origin xyz="-0.0039635 0 0.044" rpy="0 0 0" />
    <parent link="waist_yaw_link" />
    <child link="waist_roll_link" />
    <axis xyz="1 0 0" />
    <limit lower="-0.52" upper="0.52" effort="35" velocity="30" />
  </joint>
  <link name="torso_link">
    <inertial>
      <origin xyz="0.000931 0.000346 0.15082" rpy="0 0 0" />
      <mass value="6.78" />
      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
    </inertial>
    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
  </link>
  <joint name="waist_pitch_joint" type="revolute">
    <origin xyz="0 0 0" rpy="0 0 0" />
    <parent link="waist_roll_link" />
    <child link="torso_link" />
    <axis xyz="0 1 0" />
    <limit lower="-0.52" upper="0.52" effort="35" velocity="30" />
  </joint>
  <joint name="logo_joint" type="fixed">
    <origin xyz="0.0039635 0 -0.044" rpy="0 0 0" />
    <parent link="torso_link" />
    <child link="logo_link" />
  </joint>
  <link name="logo_link">
    <inertial>
      <origin xyz="0 0 0" rpy="0 0 0" />
      <mass value="0.001" />
      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
    </inertial>
    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
  </link>
  <link name="head_link">
    <inertial>
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

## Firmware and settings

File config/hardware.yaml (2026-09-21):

robot:
  manufacturer: unitree
  model: g1
  mode_machine: 5
  dof: 29
  urdf: unitree_ros/robots/g1_description/g1_29dof_rev_1_0.urdf
  calibration_reference_frame: torso_link
  available_hands:
    - dex3
    - rubber_hand
  calibration_hand: rubber_hand
  calibration_arm: left
  dummy_hand_rigid: true
  calibration_target_mount: ordered_scotch_foam_mounting_tape_on_rigid_dummy_palm
  calibration_target_tape_candidate: already_purchased_exact_sku_to_record
  calibration_target_mount_policy: qualify_by_repeated_anchor_measurement
  calibration_target_modeled_pose_on_hand_m: [0.040, -0.033, 0.000]
  calibration_target_modeled_rpy_rad: [-1.57079632679, 0.0, 0.0]
  # The cube is attached to the palm on its local -Z side. Cameras must remain
  # in the local +Z hemisphere; viewing through -Z places the hand/wrist in
  # front of the printed faces even though the cube still projects in-frame.
  calibration_target_exposed_face_normal_cube: [0.0, 0.0, 1.0]
  calibration_target_collision_envelope_m: [0.060, 0.058, 0.060]
  calibration_wrist_policy: record_and_replay_all_three_measured_wrist_joints

control:
  implementation: separate_continuous_teaching_and_replay_controllers
  upstream_reference: unitreerobotics/xr_teleoperate_G1_29_ArmController
  command_topic: rt/arm_sdk
  state_topic: rt/lowstate
  required_mode_machine: 5
  right_arm_motor_indices: [22, 23, 24, 25, 26, 27, 28]
  left_arm_motor_indices: [15, 16, 17, 18, 19, 20, 21]
  calibration_arm: left
  opposite_arm_policy: hold_measured_activation_pose
  command_rate_hz: 250
  # HOLD uses Unitree's pinned G1_29 tracking gains. GUIDE scales only the
  # calibration arm. Kp remains at the commissioned 0.5 scale; Kd is reduced to
  # 0.25 after the first collection still felt overly damped. These remain local
  # commissioning values, not an upstream Unitree freedrive recommendation.
  hold_shoulder_elbow_kp: 80.0
  hold_shoulder_elbow_kd: 3.0
  hold_wrist_kp: 40.0
  hold_wrist_kd: 1.5
  guide_kp_scale: 0.5
  guide_kd_scale: 0.25
  gain_transition_ramp_s: 1.0
  # G1 Regular/Ready locomotion mode observed through the official LocoClient.
  # mode_machine=5 identifies the 29-DoF layout and is not an FSM-mode check.
  required_regular_fsm_id: 4
  # Unitree's official G1 LocoClient maps Sit() to FSM ID 3. The isolated probe
  # established this mapping. The PC2 guard retries the read-only FSM query and
  # requires ID 3 before any seated debug ownership transition.
  required_seated_fsm_id: 3
  # FSM 3 ignored changing rt/arm_sdk targets on this robot. Seated tabletop
  # execution therefore uses Unitree's separate debug rt/lowcmd architecture:
  # release the active motion service and hold a complete measured 29-joint
  # command. Zero-displacement hardware commissioning verified takeover, normal
  # AI/FSM 0 -> Damp/FSM 1 -> Sit/FSM 3 restoration, and heartbeat-loss AI
  # restoration to verified zero-torque FSM 0. A later complete table route
  # verified changing-target seated motion and clean restoration.
  seated_table_control: debug_lowcmd
  seated_debug_failure_policy: restore_ai_verify_zero_torque_fsm_0
  seated_debug_command_topic: rt/lowcmd
  seated_debug_lowcmd_commissioned: true
  # Exact Unitree XR control term: Pinocchio RNEA at commanded q with zero
  # velocity and acceleration, written to each arm motor's tau feedforward.
  # The local rubber-hand URDF is used instead of XR's dex-hand model. The
  # 2026-08-11 zero-displacement seated run ramped this torque to full with only
  # 0.008317 rad maximum arm drift and restored FSM 0 -> 1 -> 3 cleanly.
  gravity_feedforward: pinocchio_rnea_at_commanded_q
  seated_gravity_feedforward_commissioned: true
  # Exact non-arm gains from the pinned official G1_29 XR debug controller.
  debug_body_strong_kp: 300.0
  debug_body_strong_kd: 3.0
  debug_body_weak_kp: 80.0
  debug_body_weak_kd: 3.0
  # Commissioning bound for legs/waist held at the measured seated takeover.
  debug_body_hold_position_tolerance_rad: 0.08
  debug_motion_switch_timeout_s: 5.0
  debug_motion_switch_poll_interval_s: 0.05
  guide_joint_limit_margin_rad: 0.03
  # Initial commissioning values only; hardware tests must tune/approve them.
  max_joint_velocity_rad_s: 0.2
  # Unitree's G1 arm controller uses 0.05 rad for its own home-arrival check, so
  # preserve that bound for the ownership ramp. Standing collection/replay
  # motion completes only after the command finishes, measured joints remain
  # stationary for the full dwell, and the endpoint is within this commissioned
  # tolerance. Seated table execution replaces only that final endpoint gate
  # with measured-state FCL/table/next-route validation; task accuracy is always
  # scored visually in the board frame.
  ownership_transition_position_tolerance_rad: 0.05
  motion_position_tolerance_rad: 0.08
  activation_position_tolerance_rad: 0.02
  held_arm_position_tolerance_rad: 0.02
  # Stationarity uses encoder-position evidence because raw rt/lowstate dq has
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

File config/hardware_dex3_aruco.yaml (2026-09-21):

robot:
  manufacturer: unitree
  model: g1
  mode_machine: 5
  dof: 29
  # The 29-DoF motion/FK model retains the exact mode-5 command coordinates.
  # Its right_rubber_hand frame has the same wrist-fixed transform as the
  # right Dex3 palm frame and is used only as that kinematic frame alias.
  urdf: config/urdf/g1_29dof_rev_1_0_g1pilot_collision.urdf
  calibration_reference_frame: torso_link
  available_hands: [dex3]
  calibration_hand: dex3
  calibration_arm: right
  calibration_hand_frame: right_rubber_hand
  physical_hand_frame: right_hand_palm_link
  calibration_target_mount: dex3_dorsal_two_m3_rev2
  calibration_target_dictionary: DICT_6X6_50
  calibration_target_id: 4
  opposite_hand_calibration_target_id: 5
  calibration_target_active_size_m: 0.040
  calibration_target_mount_manifest: cad/dex3_dorsal_aruco_mount/design_manifest.json
  # Nominal right_hand_palm_link_T_marker from the revision-2 CAD manifest.
  # Marker +X is across the hand, +Y points wristward, and +Z points outward.
  calibration_target_modeled_hand_T_target:
    - [0.0, -0.9998011179423463, 0.01994303289959598, 0.03681565314267739]
    - [0.0, -0.01994303289959598, -0.9998011179423463, -0.02742719713567078]
    - [1.0, 0.0, 0.0, 0.0]
    - [0.0, 0.0, 0.0, 1.0]
  calibration_target_exposed_face_normal_target: [0.0, 0.0, 1.0]
  calibration_finger_posture_model: nvidia_groot_middle_close
  calibration_finger_posture_physical_precondition: >-
    complete live-planned bilateral shoulder and finger sweep physically clear
  collision_geometry_profile: dual_dex3_marker_nvidia_middle_close_segmented_aabbs
  calibration_wrist_policy: command_all_three_measured_wrist_joints

control:
  implementation: unitree_arm_sdk_pose_executor
  upstream_reference: unitreerobotics/xr_teleoperate_G1_29_ArmController
  command_topic: rt/arm_sdk
  state_topic: rt/lowstate
  required_mode_machine: 5
  right_arm_motor_indices: [22, 23, 24, 25, 26, 27, 28]
  left_arm_motor_indices: [15, 16, 17, 18, 19, 20, 21]
  calibration_arm: right
  opposite_arm_policy: hold_measured_activation_pose
  command_rate_hz: 250
  hold_shoulder_elbow_kp: 80.0
  hold_shoulder_elbow_kd: 3.0
  hold_wrist_kp: 40.0
  hold_wrist_kd: 1.5
  guide_kp_scale: 0.5
  guide_kd_scale: 0.25
  gain_transition_ramp_s: 1.0
  required_regular_fsm_id: 4
  required_seated_fsm_id: 3
  seated_table_control: debug_lowcmd
  seated_debug_failure_policy: restore_ai_verify_zero_torque_fsm_0
  seated_debug_command_topic: rt/lowcmd
  seated_debug_lowcmd_commissioned: true
  gravity_feedforward: pinocchio_rnea_at_commanded_q
  # Unitree XR RNEA architecture with both Dex3 hands loaded; the fourteen
  # finger joints are locked at NVIDIA GR00T's middle-close calibration posture.
  gravity_model_urdf: unitree_ros/robots/g1_description/g1_29dof_with_hand_rev_1_0.urdf
  gravity_locked_joint_positions_rad:
    left_hand_thumb_0_joint: 0.0
    left_hand_thumb_1_joint: 0.7
    left_hand_thumb_2_joint: 0.7
    left_hand_middle_0_joint: -1.0
    left_hand_middle_1_joint: -1.5
    left_hand_index_0_joint: -1.0
    left_hand_index_1_joint: -1.5
    right_hand_thumb_0_joint: 0.0
    right_hand_thumb_1_joint: -0.7
    right_hand_thumb_2_joint: -0.7
    right_hand_middle_0_joint: 1.0
    right_hand_middle_1_joint: 1.5
    right_hand_index_0_joint: 1.0
    right_hand_index_1_joint: 1.5
  gravity_locked_joint_posture_source: nvlabs_groot_middle_close
  # The previous seated commissioning used rubber-hand inertias. A new
  # zero-displacement run must commission the dual-Dex3 gravity model before
  # seated tabletop execution is enabled.
  seated_gravity_feedforward_commissioned: false
  debug_body_strong_kp: 300.0
  debug_body_strong_kd: 3.0
  debug_body_weak_kp: 80.0
  debug_body_weak_kd: 3.0
  debug_body_hold_position_tolerance_rad: 0.08
  debug_motion_switch_timeout_s: 5.0
  debug_motion_switch_poll_interval_s: 0.05
  guide_joint_limit_margin_rad: 0.03
  max_joint_velocity_rad_s: 0.2
  ownership_transition_position_tolerance_rad: 0.05
  motion_position_tolerance_rad: 0.08
  activation_position_tolerance_rad: 0.02
  held_arm_position_tolerance_rad: 0.10
  settled_position_spread_rad: 0.01
  settle_dwell_s: 0.5
  lowstate_timeout_s: 0.1
  # Half of the independent 0.5 s PC2 watchdog deadline. A gap this large is
  # still a local fault and intentionally stops the heartbeat.
  control_gap_fault_s: 0.25
  acquisition_weight_ramp_s: 1.0
  release_weight_ramp_s: 1.0
  motion_timeout_s: 30.0
  clean_release_policy: return_to_per_run_activation_then_ramp_weight_to_zero
  emergency_release_policy: pc2_g1_loco_damp
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

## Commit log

2026-09-21 Consolidate current G1 calibration tools and V7 fixtures
    [FIT_ONLY_lower_left_PRINT.stl, FIT_ONLY_lower_right_PRINT.stl, FIT_ONLY_upper_left_PRINT.stl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]
2026-09-24 Introduce calibration tools with the wrist fixture and guide links
